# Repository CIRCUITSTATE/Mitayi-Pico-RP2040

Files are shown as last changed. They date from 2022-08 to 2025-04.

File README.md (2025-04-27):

# Mitayi-Pico-D1

[**Mitayi-Pico-D1**](https://github.com/CIRCUITSTATE/Mitayi-Pico-RP2040) is the first development board from **CIRCUITSTATE Electronics**. The board is based on the **RP2040** microcontroller from Raspberry Pi and is designed after the official [**Raspberry Pi Pico**](https://www.raspberrypi.com/products/raspberry-pi-pico/) board, but adds a few improvements over it. **D1** is the first design variant of Mitayi-Pico. Mitayi-Pico is not pin-compatible with the official Raspberry Pi Pico. The schematic and PCB are designed with **KiCad**, an open-source EDA tool. All the design files of Mitayi-Pico are completely open-source and released under the MIT license.

## Features & Differences

- **RP2040** dual-core, 133MHz ARM Cortex M0+ microcontroller.
- Up to 16 MB Flash memory in `SOIC-8` package.
- USB-C for power and communication.
- USB solder pads.
- **MIC5219** LDO with 3.3V, 500 mA output.
- Power indication LED.
- `RESET` button.
- `BOOTSEL` button reconfigurable as GPIO input button.
- Debug LED with GPIO solder jumper.
- Breaks out all MCU GPIO pins.
- **EXP8** expansion connector in 2x4 2.54mm pin header. Breaks out SPI, UART and I2C.
- 3-pin SWD connector.
- Uses 0402 or larger SMD packages.
- **Mitayi-Pico is not pin-compatible with the official Raspberry Pi Pico.**
- Same dimensions of 21 mm x 50 mm, with almost the same positions for mounting holes.
- Completely open-source design made with KiCad 9.

## Design

- **Parent Project:** Mitayi-Pico
- **Variant:** [Mitayi-Pico-D1](https://github.com/CIRCUITSTATE/Mitayi-Pico-RP2040)
- **Author:** Vishnu Mohanan (@vishnumaiea)
- **Latest Revision:** `R0.6`
- **Layer Count:** 2
- **Thickness:** 1 mm
- **Dimensions:** 51 x 21 mm
- **EDA Tool:** KiCad V9
- **License:** MIT

## Contributing

If you would like to contribute this project, you are welcome to post issues and feature requests on the **Issues** page. If you fork this project and created a new variant, you can let us know about it and get a unique identifier assigned for your project. The ID takes the following form.

```
Y<digit><letter><digit>
```

`Y` – Constant prefix.

`<digit>` – Digits from 0–9

`<letter>` – Characters from A–Z.

**Examples:**

```
Y1A1
Y1A2
```

## References

- [**Raspberry Pi Pico** - Product Page](https://www.raspberrypi.com/products/raspberry-pi-pico/)

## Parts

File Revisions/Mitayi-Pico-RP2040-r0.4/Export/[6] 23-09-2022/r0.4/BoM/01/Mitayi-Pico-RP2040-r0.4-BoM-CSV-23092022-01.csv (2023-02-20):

Id | Designator | Package | Quantity | Designation | Supplier and ref
1 | JP5 | Solder-Jumper_2P_Open_0402 | 1 | DEB_EN
2 | D2 | LED_0603_1608Metric | 1 | DBG_LED
3 | C17,C18 | C_0402_1005Metric_Pad0.74x0.62mm_HandSolder | 2 | 30pF
4 | C12,C6,C11,C10,C2,C1,C9,C8,C7 | C_0402_1005Metric_Pad0.74x0.62mm_HandSolder | 9 | 100n
5 | C13,C15 | C_0603_1608Metric | 2 | 10u
6 | C19,C5,C4 | C_0402_1005Metric_Pad0.74x0.62mm_HandSolder | 3 | 1u
7 | R2,R10 | R_0402_1005Metric_Pad0.72x0.64mm_HandSolder | 2 | 1k
8 | R7,R8 | R_0402_1005Metric_Pad0.72x0.64mm_HandSolder | 2 | 470R
9 | H3,H2,H4,H1 | MountingHole_2.2mm_M2 | 4 | MountingHole
10 | U3 | RP2040-QFN-56 | 1 | RP2040
11 | R5,R6 | R_0402_1005Metric_Pad0.72x0.64mm_HandSolder | 2 | 27R
12 | U1 | SOIC-8_5.23x5.23mm_P1.27mm | 1 | W25Q128JVS
13 | R1 | R_0402_1005Metric_Pad0.72x0.64mm_HandSolder | 1 | DNP
14 | J5 | PinHeader_1x03_P2.54mm_Vertical | 1 | SWD
15 | JP1 | Solder-Jumper_2P_Open_0402 | 1 | AREF_SEL
16 | R9 | R_0402_1005Metric_Pad0.72x0.64mm_HandSolder | 1 | 10K
17 | J2 | Korean-Hroparts-Elec_TYPE-C-31-M-12 | 1 | USB_C_Receptacle_USB2.0
18 | C16 | C_0402_1005Metric_Pad0.74x0.62mm_HandSolder | 1 | 470pF
19 | JP4 | Solder-Jumper_2P_Open_0402 | 1 | VR1_CE
20 | R4,R3,R11 | R_0402_1005Metric_Pad0.72x0.64mm_HandSolder | 3 | 5.1K
21 | Y1 | Crystal_SMD_3225-4Pin_3.2x2.5mm | 1 | YIC-12M20P2/XT324-10/10
22 | D1 | D_SOD-323_HandSoldering | 1 | PMEG4005EJ
23 | D3 | LED_0603_1608Metric | 1 | POW_LED
24 | J6 | USB_Micro-B_Molex-105017-0001 | 1 | USB_B_Micro
25 | SW1 | CK_SW_SPST_UK-B0273-SP25Y | 1 | Reset
26 | J3 | PinHeader_1x20_2H_P2.54mm_Vertical | 1 | Header_1
27 | C14 | CP_EIA-2012-12_Kemet-R | 1 | 2.2uF
28 | U2 | SOT-23-5 | 1 | MIC5219-3.3YM5
29 | SW2 | CK_SW_SPST_UK-B0273-SP25Y | 1 | UBUT
30 | J1 | PinHeader_2x04_P2.54mm_Vertical | 1 | EXP8
31 | JP6 | Solder-Jumper_3P_Open_0402 | 1 | UBUT_SEL
32 | J4 | PinHeader_1x20_2H_P2.54mm_Vertical | 1 | Header_2

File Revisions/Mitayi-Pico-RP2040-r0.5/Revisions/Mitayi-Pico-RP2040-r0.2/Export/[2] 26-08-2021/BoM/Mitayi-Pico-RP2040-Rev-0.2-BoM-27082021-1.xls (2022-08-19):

Id | Reference | Value | Package | Quantity | Notes | MPN | LCSC Part # | Unit Price (INR) | Order Price (INR) | Min\Mult Order Qty
1 | C11,C5,C10,C9,C2,C1,C17,C8,C7,C6 | 100n | C_0402_1005Metric_Pad0.74x0.62mm_HandSolder | 10 |  | CC0402KRX5R6BB104 (https://lcsc.com/product-detail/Multilayer-Ceramic-Capacitors-MLCC-SMD-SMT_YAGEO-CC0402KRX5R6BB104_C129131.html) | C129131 (https://lcsc.com/product-detail/Multilayer-Ceramic-Capacitors-MLCC-SMD-SMT_YAGEO-CC0402KRX5R6BB104_C129131.html) | 0.3765 | 3.77 | 50\50
2 | C12 | 2.2uF | CP_EIA-2012-12_Kemet-R | 1 |  | CA45-A-16V-2.2uF-M (https://lcsc.com/product-detail/Tantalum-Capacitors_CEC-Shenzhen-Zhenhua-XinYun-Elec-CA45-A-16V-2-2uF-M_C688947.html) | C688947 (https://lcsc.com/product-detail/Tantalum-Capacitors_CEC-Shenzhen-Zhenhua-XinYun-Elec-CA45-A-16V-2-2uF-M_C688947.html) | 6.9761 | 6.98 | 5\5
3 | C14,C13 | 10u | C_0603_1608Metric | 2 |  | LMK107BJ106MALTD (https://lcsc.com/product-detail/Multilayer-Ceramic-Capacitors-MLCC-SMD-SMT_Taiyo-Yuden-LMK107BJ106MALTD_C18800.html) | C18800 (https://lcsc.com/product-detail/Multilayer-Ceramic-Capacitors-MLCC-SMD-SMT_Taiyo-Yuden-LMK107BJ106MALTD_C18800.html) | 1.0926 | 2.19 | 50\50
4 | C15 | 470pF | C_0402_1005Metric_Pad0.74x0.62mm_HandSolder | 1 |  | 0402N471J500CT (https://lcsc.com/product-detail/Multilayer-Ceramic-Capacitors-MLCC-SMD-SMT_Walsin-Tech-Corp-0402N471J500CT_C295986.html) | C295986 (https://lcsc.com/product-detail/Multilayer-Ceramic-Capacitors-MLCC-SMD-SMT_Walsin-Tech-Corp-0402N471J500CT_C295986.html) | 0.192 | 0.19 | 100\100
5 | C16,C4,C3 | 1u | C_0402_1005Metric_Pad0.74x0.62mm_HandSolder | 3 |  | 0402F105M100NT (https://lcsc.com/product-detail/Multilayer-Ceramic-Capacitors-MLCC-SMD-SMT_FH-Guangdong-Fenghua-Advanced-Tech-0402F105M100NT_C157621.html) | C157621 (https://lcsc.com/product-detail/Multilayer-Ceramic-Capacitors-MLCC-SMD-SMT_FH-Guangdong-Fenghua-Advanced-Tech-0402F105M100NT_C157621.html) | 0.2289 | 0.69 | 100\100
6 | C18,C19 | 27p | C_0402_1005Metric_Pad0.74x0.62mm_HandSolder | 2 |  | 0402CG270J500NT (https://lcsc.com/product-detail/Multilayer-Ceramic-Capacitors-MLCC-SMD-SMT_FH-Guangdong-Fenghua-Advanced-Tech-0402CG270J500NT_C1557.html) | C1557 (https://lcsc.com/product-detail/Multilayer-Ceramic-Capacitors-MLCC-SMD-SMT_FH-Guangdong-Fenghua-Advanced-Tech-0402CG270J500NT_C1557.html) | 0.1108 | 0.22 | 100\100
7 | D1 | DEBUG_LED | C_0603_1608Metric_Pad1.08x0.95mm_HandSolder | 1 |  | LTST-C191KSKT (https://lcsc.com/product-detail/Light-Emitting-Diodes-LED_Lite-On-LTST-C191KSKT_C125100.html) | C125100 (https://lcsc.com/product-detail/Light-Emitting-Diodes-LED_Lite-On-LTST-C191KSKT_C125100.html) | 1.8234 | 1.82 | 20\20
8 | D2 | MBR1020VL | D_SOD-123F | 1 |  | 1N5819W (https://lcsc.com/product-detail/Schottky-Barrier-Diodes-SBD_Shandong-Jingdao-Microelectronics-1N5819W_C169540.html) | C169540 (https://lcsc.com/product-detail/Schottky-Barrier-Diodes-SBD_Shandong-Jingdao-Microelectronics-1N5819W_C169540.html) | 7.21 | 7.21 | 5\5
9 | J1 | USB_C_Receptacle_USB2.0 | Korean-Hroparts-Elec_TYPE-C-31-M-12 | 1 |  | TYPE-C-31-M-12 (https://lcsc.com/product-detail/USB-Connectors_Korean-Hroparts-Elec-TYPE-C-31-M-12_C165948.html) | C165948 (https://lcsc.com/product-detail/USB-Connectors_Korean-Hroparts-Elec-TYPE-C-31-M-12_C165948.html) | 23.298 | 23.3 | 1\1
10 | J2 | Header_1 | PinHeader_1x20_2H_P2.54mm_Vertical | 1 | DNP |  |  |  |  | 100\100
11 | J3 | Header_2 | PinHeader_1x20_2H_P2.54mm_Vertical | 1 | DNP |  |  |  |  | 100\100
12 | J4 | USB Boot | R_0603_1608Metric_Pad0.98x0.95mm_HandSolder | 1 | DNP |  |  |  |  | 100\100
13 | J5 | SWD | PinHeader_1x03_P2.54mm_Vertical | 1 | DNP |  |  |  |  | 100\100
14 | J6 | USB_B_Micro | USB_Micro-B_Molex-105017-0001 | 1 |  | MicroXNJ (https://lcsc.com/product-detail/USB-Connectors_SHOU-HAN-MicroXNJ_C404969.html) | C404969 (https://lcsc.com/product-detail/USB-Connectors_SHOU-HAN-MicroXNJ_C404969.html) |  |  | 100\100
15 | JP1 | VR1_IN | R_0402_1005Metric | 1 | DNP |  |  |  |  | 5\5
16 | JP2 | VR2_OUT | R_0402_1005Metric | 1 | DNP |  |  |  |  | 5\5
17 | JP3 | VR1_BP | R_0402_1005Metric | 1 | DNP |  |  |  |  | 5\5
18 | JP4 | VR1_CE | R_0402_1005Metric | 1 | DNP
19 | JP5 | AREF | R_0402_1005Metric | 1 | DNP
20 | JP6 | DEB_EN | R_0402_1005Metric | 1 | DNP
21 | R1 | DNP | R_0402_1005Metric_Pad0.72x0.64mm_HandSolder | 1 | DNP
22 | R2,R3 | 1k | R_0402_1005Metric_Pad0.72x0.64mm_HandSolder | 2 |  | RMC04021K1%N (https://lcsc.com/product-detail/Chip-Resistor-Surface-Mount_TyoHM-RMC04021K1-N_C269675.html) | C269675 (https://lcsc.com/product-detail/Chip-Resistor-Surface-Mount_TyoHM-RMC04021K1-N_C269675.html) | 0.1625 | 0.33
23 | R4 | 470R | R_0402_1005Metric_Pad0.72x0.64mm_HandSolder | 1 |  | RTT024700FTH (https://lcsc.com/product-detail/Chip-Resistor-Surface-Mount_RALEC-RTT024700FTH_C103054.html) | C103054 (https://lcsc.com/product-detail/Chip-Resistor-Surface-Mount_RALEC-RTT024700FTH_C103054.html) | 0.0591 | 0.06
24 | R5,R6 | 27R | R_0402_1005Metric_Pad0.72x0.64mm_HandSolder | 2 |  | 0402WGF270JTCE (https://lcsc.com/product-detail/Chip-Resistor-Surface-Mount_UNI-ROYAL-Uniroyal-Elec-0402WGF270JTCE_C25100.html) | C25100 (https://lcsc.com/product-detail/Chip-Resistor-Surface-Mount_UNI-ROYAL-Uniroyal-Elec-0402WGF270JTCE_C25100.html) | 0.0517 | 0.1
25 | R8,R7 | 5.1K | R_0402_1005Metric_Pad0.72x0.64mm_HandSolder | 2 |  | 0402WGF5101TCE (https://lcsc.com/product-detail/Chip-Resistor-Surface-Mount_UNI-ROYAL-Uniroyal-Elec-0402WGF5101TCE_C25905.html) | C25905 (https://lcsc.com/product-detail/Chip-Resistor-Surface-Mount_UNI-ROYAL-Uniroyal-Elec-0402WGF5101TCE_C25905.html) | 0.0517 | 0.1
26 | R9 | 10K | R_0402_1005Metric_Pad0.72x0.64mm_HandSolder | 1 |  | RC0402FR-0710KL (https://lcsc.com/product-detail/Chip-Resistor-Surface-Mount_YAGEO-RC0402FR-0710KL_C60490.html) | C60490 (https://lcsc.com/product-detail/Chip-Resistor-Surface-Mount_YAGEO-RC0402FR-0710KL_C60490.html) | 0.0591 | 0.06
27 | SW1 | Reset | CK_SW_SPST_UK-B0273-SP25Y | 1 |  | UK-B0273-SP25Y (https://lcsc.com/product-detail/Tactile-Switches_USAKRO-UK-B0273-SP25Y_C493285.html) | C493285 (https://lcsc.com/product-detail/Tactile-Switches_USAKRO-UK-B0273-SP25Y_C493285.html) | 9.1981 | 9.2
28 | U1 | NCP1117-3.3_SOT223 | SOT-223-3_TabPin2 | 1 |  | LD1117-3.3 (https://lcsc.com/product-detail/Linear-Voltage-Regulators-LDO_UMW-Youtai-Semiconductor-Co-Ltd-LD1117-3-3_C347229.html) | C347229 (https://lcsc.com/product-detail/Linear-Voltage-Regulators-LDO_UMW-Youtai-Semiconductor-Co-Ltd-LD1117-3-3_C347229.html)
29 | U2 | MIC5219-3.3YM5 | SOT-23-5 | 1 |  | ME6217C33M5G (https://lcsc.com/product-detail/Linear-Voltage-Regulators-LDO_MICRONE-Nanjing-Micro-One-Elec-ME6217C33M5G_C427602.html) | C427602 (https://lcsc.com/product-detail/Linear-Voltage-Regulators-LDO_MICRONE-Nanjing-Micro-One-Elec-ME6217C33M5G_C427602.html) | 7.7143 | 7.71
30 | U3 | W25Q128JVS | SOIC-8_5.23x5.23mm_P1.27mm | 1 |  | W25Q128JVSIQ (https://lcsc.com/product-detail/NOR-FLASH_Winbond-Elec-W25Q128JVSIQ_C113767.html) | C113767 (https://lcsc.com/product-detail/NOR-FLASH_Winbond-Elec-W25Q128JVSIQ_C113767.html) | 57 | 57
31 | U4 | RP2040 | RP2040-QFN-56 | 1 |  | RP2040-7-500 |  | 80 | 80
32 | Y1 | ABLS-12.000MHZ-B4-T | Crystal_SMD_3225-4Pin_3.2x2.5mm | 1 |  | S3212000181080 (https://lcsc.com/product-detail/Crystals_JGHC-S3212000181080_C390764.html) | C390764 (https://lcsc.com/product-detail/Crystals_JGHC-S3212000181080_C390764.html) | 8.5633 | 8.56
 |  |  |  |  |  |  | Total

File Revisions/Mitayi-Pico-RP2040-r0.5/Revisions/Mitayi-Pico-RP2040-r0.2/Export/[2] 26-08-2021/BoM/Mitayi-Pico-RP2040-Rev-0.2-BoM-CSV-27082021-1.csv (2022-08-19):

Id | Designator | Package | Quantity | Designation | Supplier and ref
1 | JP6 | R_0402_1005Metric | 1 | DEB_EN
2 | D1 | C_0603_1608Metric_Pad1.08x0.95mm_HandSolder | 1 | DEBUG_LED
3 | C18,C19 | C_0402_1005Metric_Pad0.74x0.62mm_HandSolder | 2 | 27p
4 | C11,C5,C10,C9,C2,C1,C17,C8,C7,C6 | C_0402_1005Metric_Pad0.74x0.62mm_HandSolder | 10 | 100n
5 | J4 | R_0603_1608Metric_Pad0.98x0.95mm_HandSolder | 1 | USB Boot
6 | JP3 | R_0402_1005Metric | 1 | VR1_BP
7 | C14,C13 | C_0603_1608Metric | 2 | 10u
8 | C16,C4,C3 | C_0402_1005Metric_Pad0.74x0.62mm_HandSolder | 3 | 1u
9 | R2,R3 | R_0402_1005Metric_Pad0.72x0.64mm_HandSolder | 2 | 1k
10 | R4 | R_0402_1005Metric_Pad0.72x0.64mm_HandSolder | 1 | 470R
11 | H3,H2,H4,H1 | MountingHole_2.2mm_M2 | 4 | MountingHole
12 | Y1 | Crystal_SMD_3225-4Pin_3.2x2.5mm | 1 | ABLS-12.000MHZ-B4-T
13 | U4 | RP2040-QFN-56 | 1 | RP2040
14 | R5,R6 | R_0402_1005Metric_Pad0.72x0.64mm_HandSolder | 2 | 27R
15 | U3 | SOIC-8_5.23x5.23mm_P1.27mm | 1 | W25Q128JVS
16 | R1 | R_0402_1005Metric_Pad0.72x0.64mm_HandSolder | 1 | DNF
17 | G*** | OSHW-Logo-4x3.6mm | 1 | LOGO
18 | JP1 | R_0402_1005Metric | 1 | VR1_IN
19 | J5 | PinHeader_1x03_P2.54mm_Vertical | 1 | SWD
20 | R9 | R_0402_1005Metric_Pad0.72x0.64mm_HandSolder | 1 | 10K
21 | J1 | Korean-Hroparts-Elec_TYPE-C-31-M-12 | 1 | USB_C_Receptacle_USB2.0
22 | C15 | C_0402_1005Metric_Pad0.74x0.62mm_HandSolder | 1 | 470pF
23 | JP4 | R_0402_1005Metric | 1 | VR1_CE
24 | R8,R7 | R_0402_1005Metric_Pad0.72x0.64mm_HandSolder | 2 | 5.1K
25 | D2 | D_SOD-123F | 1 | MBR1020VL
26 | J6 | USB_Micro-B_Molex-105017-0001 | 1 | USB_B_Micro
27 | SW1 | CK_SW_SPST_UK-B0273-SP25Y | 1 | Reset
28 | J2 | PinHeader_1x20_2H_P2.54mm_Vertical | 1 | Header_1
29 | C12 | CP_EIA-2012-12_Kemet-R | 1 | 2.2uF
30 | JP5 | R_0402_1005Metric | 1 | AREF
31 | U2 | SOT-23-5 | 1 | MIC5219-3.3YM5
32 | U1 | SOT-223-3_TabPin2 | 1 | NCP1117-3.3_SOT223
33 | G*** | Circuitstate-Logomark-27x3.8mm | 1 | LOGO
34 | JP2 | R_0402_1005Metric | 1 | VR2_OUT
35 | J3 | PinHeader_1x20_2H_P2.54mm_Vertical | 1 | Header_2

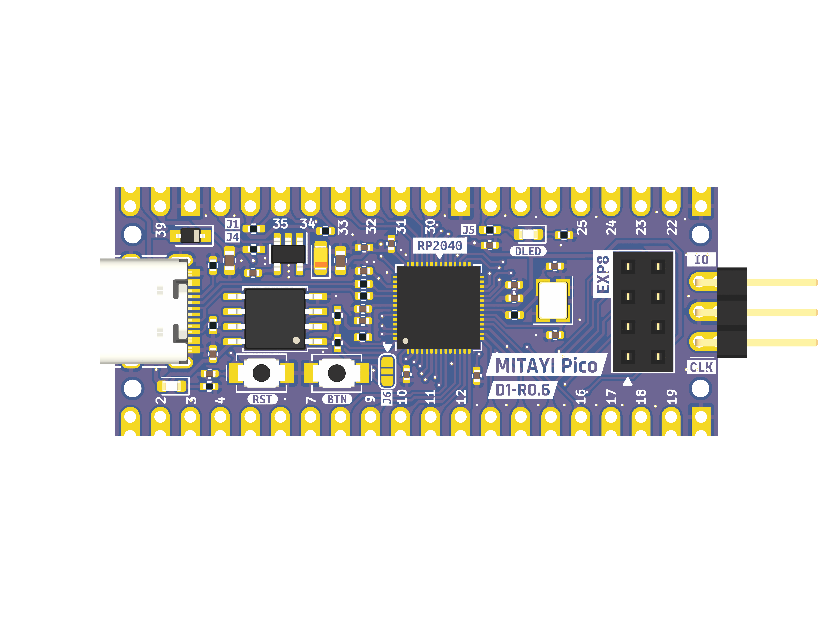
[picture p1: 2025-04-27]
Export/R0.6/2025-04-27/Renders/Mitayi-Pico-D1-R0.6-PCB-Parts-Front-27042025-1.png

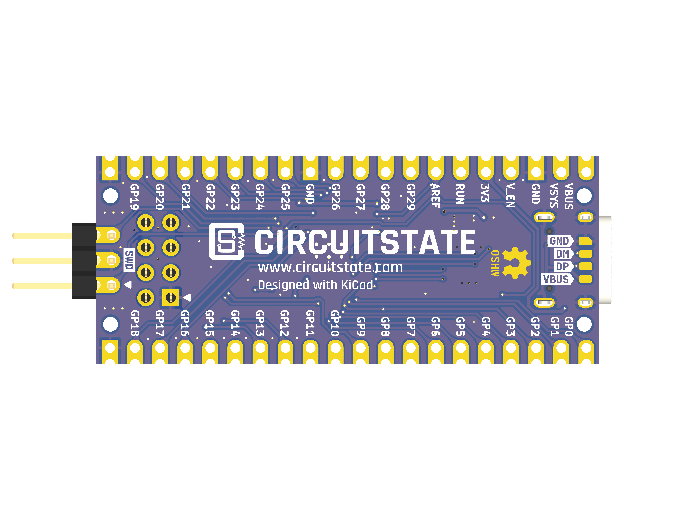
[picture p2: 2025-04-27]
Export/R0.6/2025-04-27/Renders/Mitayi-Pico-D1-R0.6-PCB-Parts-Back-27042025-1.png

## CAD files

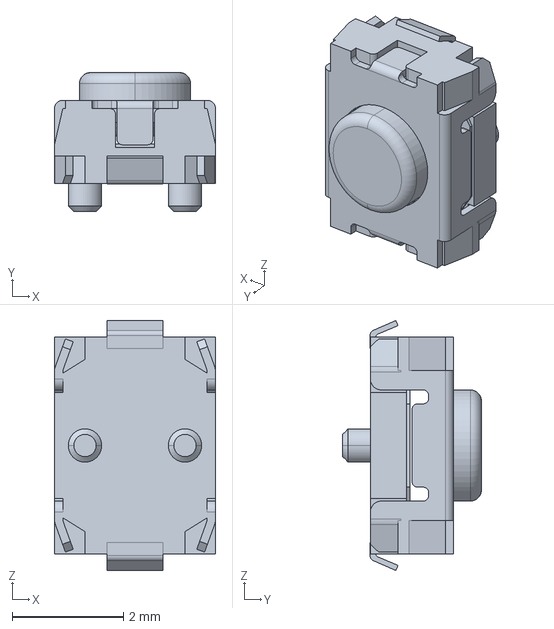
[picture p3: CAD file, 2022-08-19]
Revisions/Mitayi-Pico-RP2040-r0.5/Revisions/Mitayi-Pico-RP2040-r0.2/Parts/3D-Shapes/C&K-Tactile-Switch-PTS820J20KPSMTRLFS.stp
2.90 x 2.50 x 4.50 mm

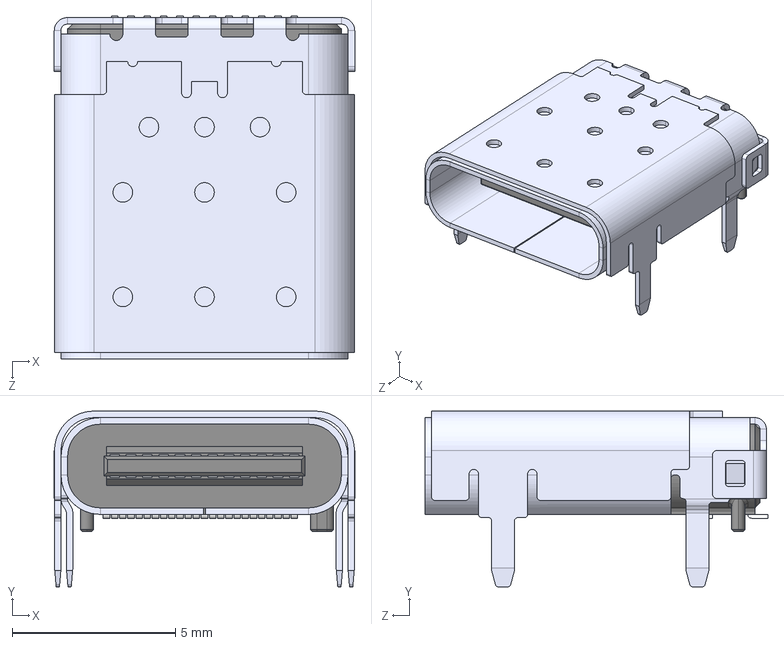
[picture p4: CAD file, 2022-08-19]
Revisions/Mitayi-Pico-RP2040-r0.5/Revisions/Mitayi-Pico-RP2040-r0.2/Parts/3D-Shapes/Amphenol-USB-Tyep-C-Receptacle-12401598E4#2A.STEP
9.20 x 5.38 x 10.5 mm

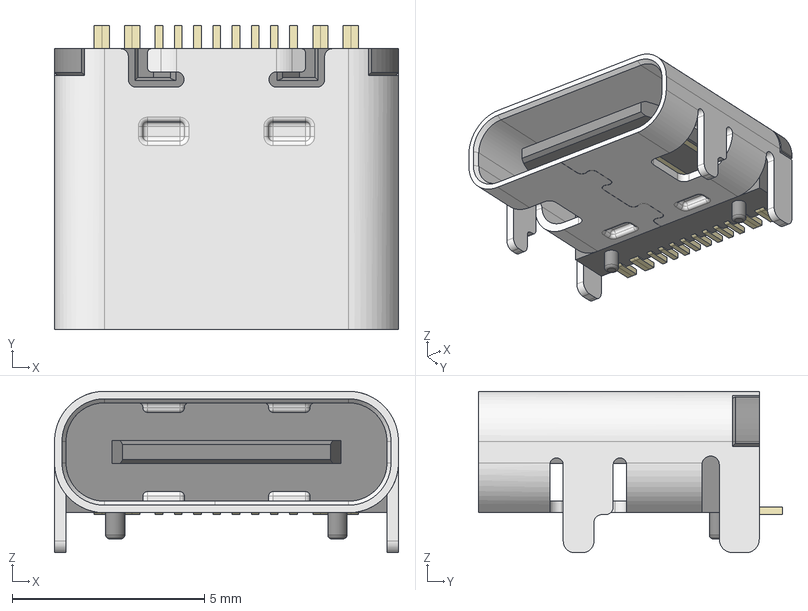
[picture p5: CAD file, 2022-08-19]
Revisions/Mitayi-Pico-RP2040-r0.5/Revisions/Mitayi-Pico-RP2040-r0.2/Parts/3D-Shapes/USB_Receptacle_HRO_TYPE-C-31-M-12.step
8.95 x 7.90 x 4.20 mm

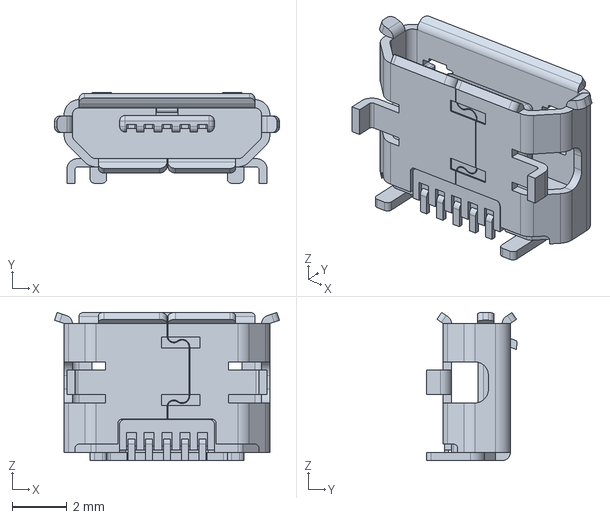
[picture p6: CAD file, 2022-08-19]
Revisions/Mitayi-Pico-RP2040-r0.5/Revisions/Mitayi-Pico-RP2040-r0.2/Parts/3D-Shapes/Molex-Micro-USB-Receptacle-1050170001.stp
8.20 x 3.30 x 5.40 mm

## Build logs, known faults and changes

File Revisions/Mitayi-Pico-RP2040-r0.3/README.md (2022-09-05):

View this project on [CADLAB.io](https://cadlab.io/project/25932). 





# Mitayi Pico r0.2

**Mitayi Pico** is the first development board from **CIRCUITSTATE Electronics**. It is a small development board based on the **RP2040** microcontroller from Raspberry Pi. The board is designed after the official Pico board from Raspberry Pi, but adds a few improvements over it.

The schematic and PCB are designed with **KiCad**, an open-source EDA tool. All the design files of Mitayi Pico are completely open-source and released under the MIT license.

## Features & Differences

* RP2040 dual-core, 133MHz ARM Cortex M0+ microcontroller.
* 16MB Flash memory in SOIC-8 package.
* Dual USB port options; Type-C and Micro-USB.
* Dual voltage regulators; AMS1117 and MIC5219.
* Reset button.
* Solder jumper on debug LED.
* Breaks out all GPIO pins.
* Uses 0402 or larger SMD packages.
* Component references on the silkscreen.
* **Mitayi-Pico is not pin-compatible with Raspberry Pico.**
* Same dimensions of 21 mm x 50 mm, with almost the same positions for mounting holes.
* Completely open-source design made with KiCad 6.

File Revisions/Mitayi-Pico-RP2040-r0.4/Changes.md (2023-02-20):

#
### **+05:30 09:54:46 AM 21-09-2022, Wednesday**

  * The r0.3 PCB looks so complicated with its routing. There are 180+ vias for a rather simple board. So I am going to remove all the tracks and start routing afresh. The r0.3 will be saved for reference anyway.

  * Starts 📢 **r0.4**.

#
### **+05:30 05:47:05 PM 05-09-2022, Monday**

  * Added new version info.
  * Added license info.
  * Connected with [CADLAB.io](https://cadlab.io/project/25932). 
  
#
### **+05:30 05:33:45 PM 27-08-2022, Saturday**

  * The crystal I selected was `YIC-12M20P2/XT324-10/10` from YIC. This is a **12MHz** crystal with 20pF required load capacitance. The four pin crystal has signals on the pins `1` and `3`. But unfortunately the r0.2 had the connections to pins `1` and `2`. Not only that, the `GND` pins of the crystals were never connected. I had to apply a jumper-fix on the r0.2 board as a temporary workaround to get the board working.

  * The capacitor value for the crystal has been changed to **20pF** from 25pF. This is because I thought the capacitors were the problem. RP2040 works fine with 20pF. The approximate capacitor value required is 30pF according to the calculations. 

  * Added a second push-button that can be selected between **Reset** (`RUN`) or **GPIO** (`GPIO2`) functions. The Reset function will only be needed rarely (for example, I used it to recover the RP2040 from a *soft-brick* after I changed the clock selection to 300MHz in the Arduino IDE). So in all other cases, the user can use the push-button as a user input button.

  * I also soldered the `R1` (10K) thinking that could have been the issue. Adding it did not change anything and the board works fine with that in place. R1 is only recommended for some versions of the Flash chip.

  * Removed the secondary voltage regulator.

  * Removed `AREF_VDD` jumper. It is now connected to 3.3V.

  * Starts 📢 **r0.3**.

#
### **+05:30 08:46:57 PM 19-08-2022, Friday**

  Added new `Revisions` folder. When a revision is completed, the projected can be saved to this folder using the **Save As** option in KiCad. This is in addition to generating a git revision. The project must be saved with the revision number at the end, for example ***"Mitayi-Pico-RP2040-r0.2"***. KiCad will complain about recursive folders but you can ignore them. Just delete the recursive `Revisions` folder from the the project that was just saved to the new `Revisions` folder.

  I just saved the version **🎯 r0.2**. Revisions, once saved, should not be modified. Make all the modifications on the root project.

#
### **+05:30 07:03:26 PM 26-08-2021, Thursday**

  I made a few mistakes in the v0.1 design. Some of the vias were placed on top of the pads. While this is not a big issue, PCBWay complained about this. They said the solder mask won't be applied on such vias, which is okay. Still, placing vias on pads is not a good idea. So I modified the design and moved all the vias from pads.

  Another issue is, whenever I am trying to run DRC check, KiCad would crash and leave some ghost processes that I can not terminate. I suspect the DRC crashes because the board has filleted tracks. Launching KiCad after crash is not a problem. It works fine after that. But I am not able to run DRC 😟

  Other than that, I added the Diode to VBUS and created the new VSYS signal. The pinouts has been changed. I removed BOOT_SEL from the header. Also, the supply pin side on the header is now compatible with RPi Pico. I am not going to add TVS diodes on the USB lines yet.

  Some of the via drill sizes were less than 0.3mm. I have now changed all of them to 0.5/0.3mm.

  I am going to keep the few filleted tracks and going to generate new Gerbers. Let's see what happens. This will be **🎯 r0.2**

#
### **+05:30 10:41:48 PM 25-08-2021, Wednesday**

  **Mitayi Pico** is an improved version of **Raspberry Pi Pico**. Mitayi Pico is based on the minimal design for **RP2040** published by RPi. Many cost cutting decisions were went into the design of RPi Pico. Lack of USB Type-C and Reset button are some of that. Mitayi Pico address that and many other limitations of RPi Pico. The differences are,

  1. The original Pico PCB design is created using Altium and files are available for download. But a similar design based on any affordable open source software such as KiCad was not available. Only the minimal board design was available.

  2. RPi Pico doesn't break out all the pins. Mitayi Pico does.

  3. RPi Pico uses buck-boost converter, which can be hard to find or costly. I wanted normal LDOs. Mitayi Pico has that + it has dual regulator option.

  4. RPi Pico's components are small (0201), making it harder to hand-solder. Mitayi uses 0402 and larger packages.

  5. RPi Pico only has Micro-USB. Mitayi Pico has both Type-C and Micro-USB options.

  6. Flash memory chip package is small and hard to hand-solder when we want to change the capacity. Mitayi uses SOIC-8 package which is easily solderable.

  7. RPi Pico doesn't have a RESET button. Mitayi does.

  8. RPi Pico and Mitayi Pico have different pinouts.

  9. Debug LED has solder jumper to disconnect it from the GPIO pin.

  10. RPi Pico and Mitayi Pico share the same dimensions of 21 mm x 50 mm, with almost the same positions for mounting holes.

  11. Component references are not present on the silkscreen of RPi Pico. Mitayi Pico has all the reference to help in manual assembly.

  The word "Mitayi" means Confectionary in Malayalam and Hindi. Mitayi will be a series of boards **CIRCUITSTATE Electronics** will develop. I am still not sure whether to name the new board "Pico" because that might create confusion with the original Pico. I have to find a unique name.

  I have finished the **🎯 v0.1** of the Pico. But it needs some changes. I will commit this version to be used as the base. The changes needed are,

  1. I need to add a reverse protection diode MBR120 to the VBUS line. This will create a new signal VSYS. It has to be broken out, replacing V_EN from the header.

  2. Have to add USB data line TVS diodes.

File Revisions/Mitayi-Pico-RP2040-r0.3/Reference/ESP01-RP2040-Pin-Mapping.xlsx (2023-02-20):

ESP01 | RP2040 | Functions | Arduino
VCC (8) | 3.3V (8)
GND (1) | GND (1)
TXD (5) | GP9 (2) | SCL0, RX1, SPI1-CS | RX2
RXD (4) | GP8 (7) | SDA0, TX1, SPI1-RX | TX2
RST (7) | GP14 (6) | SDA1, CTS0, SPI1-SCK | SPI1-SCK
CE (6) | GP13 (4) | SCL0, RX0, SPI1-CS | SPI1-CS
GPIO2 (2) | GP12 (3) | SDA0, TX0, SPI1-RX | SPI1-CIPO
GPIO0 (3) | GP15 (5) | SCL1, RTS1, SPI1-TX | SPI1-COPI

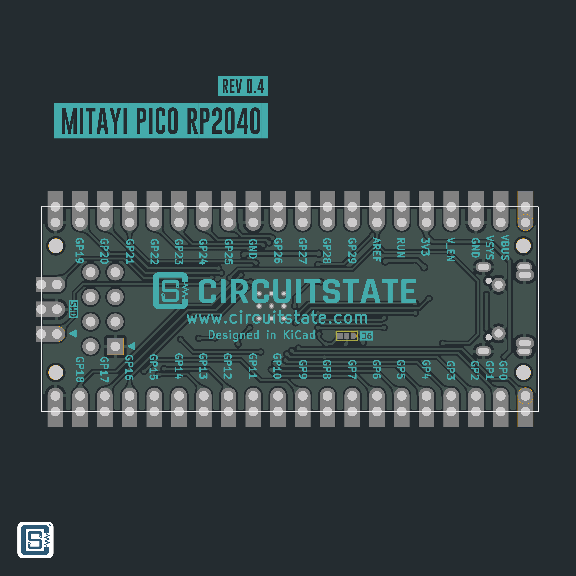
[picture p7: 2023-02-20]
Revisions/Mitayi-Pico-RP2040-r0.4/Export/[6] 23-09-2022/r0.4/Images/Mitayi-Pico-RP2040-r0.4-PCB-01-Back-2.png

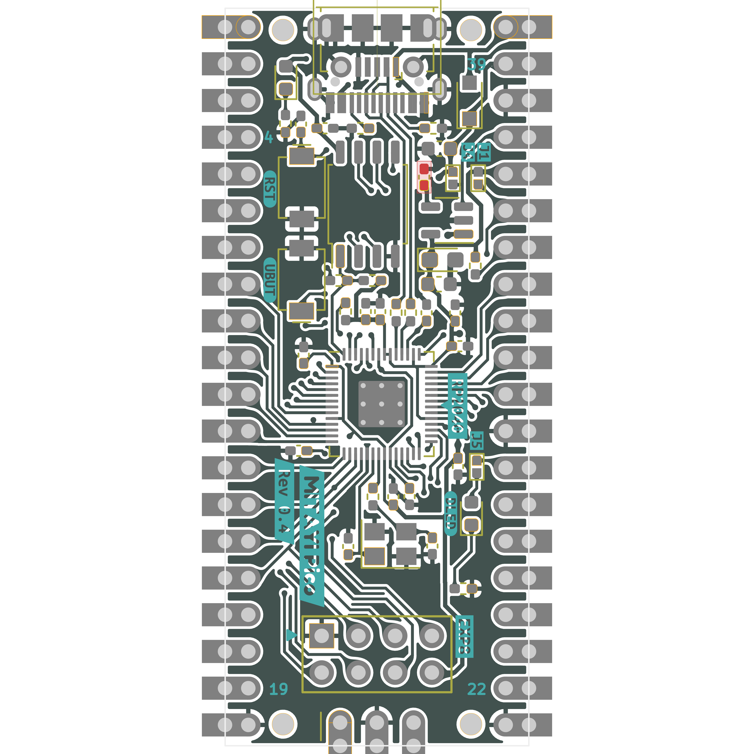
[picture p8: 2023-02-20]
Revisions/Mitayi-Pico-RP2040-r0.5/Revisions/Mitayi-Pico-RP2040-r0.4/Export/[6] 23-09-2022/r0.4/Images/Mitayi Pico - PCB.0.4.F (1).png

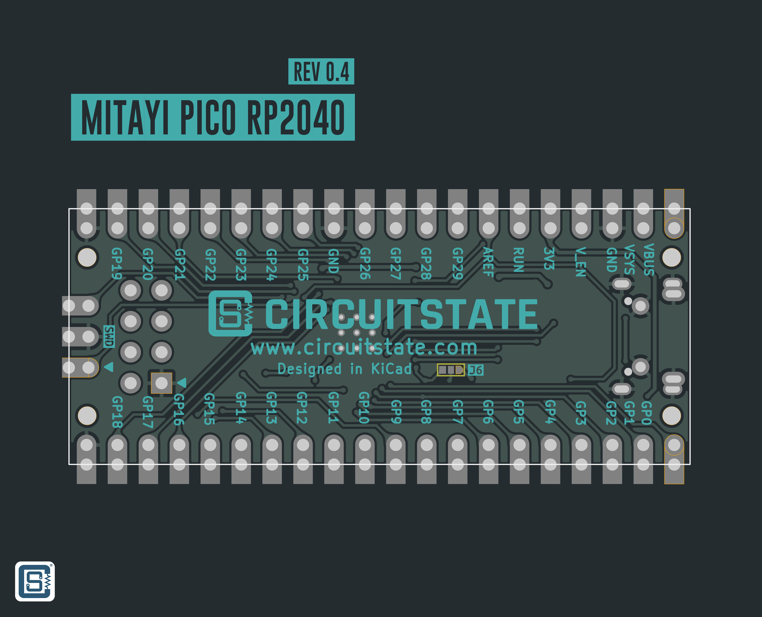
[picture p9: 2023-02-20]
Revisions/Mitayi-Pico-RP2040-r0.4/Export/[6] 23-09-2022/r0.4/Images/Mitayi-Pico-RP2040-r0.4-PCB-01-Back-1.png

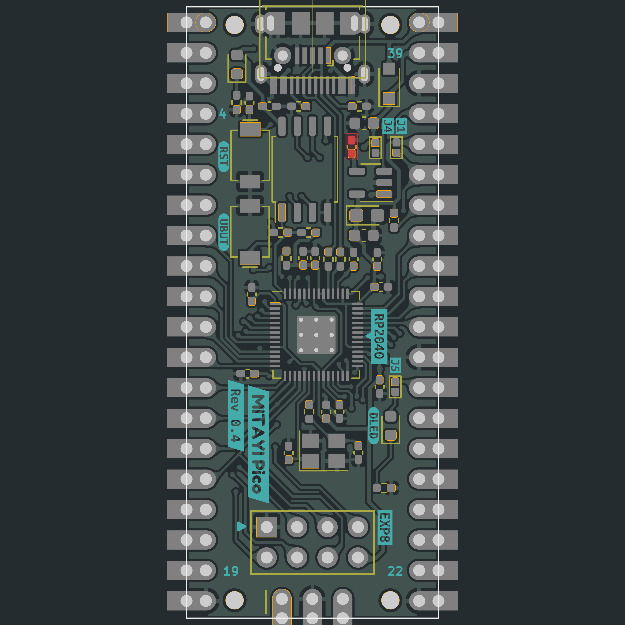
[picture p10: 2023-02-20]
Revisions/Mitayi-Pico-RP2040-r0.5/Revisions/Mitayi-Pico-RP2040-r0.4/Export/[6] 23-09-2022/r0.4/Images/Mitayi Pico - PCB.0.4.F.png

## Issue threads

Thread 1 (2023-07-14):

Missing Symbol / Footprint

hmaerki, 2023-07-14:
Hi Vishnu

I had a look at ths PCB and I like it a lot!

There is a symbol of U3 missing `CIRCUITSTATE-Microcontrollers:RP2040`
These footprints are missing:
CIRCUITSTATE-QFN:RP2040-QFN-56
JP5 (CIRCUITSTATE_Jumper_SMD:Solder-Jumper_2P_Open_0402
SW2 (CIRCUITSTATE_Switch_SMD:CK_SW_SPST_UK-B0273-SP25YG
CIRCUITSTATE-Graphics:Circuitstate-Logomark-27x3.8mm

Could you add this symbol/footprint please.

Thank you
    Hans

Keep going with you excellent work!

vishnumaiea, 2023-07-14:
Hi Hans. Glad you like it. The footprints you have mentioned are custom footprints I designed for the board. They were saved to local libraries in my system, not to the project folder. So you won't find them in the project folder. But, all footprints must be cached on the design files, even if they are not in your system. You can open a footprint in the footprint editor and "Save As" it somewhere else if you plan to reuse them on a different project.

Does KiCad throw any errors while trying to load the files on your side? If yes, could you please share a screenshot? I hope you are using the latest KiCad release.

Please let me know if this helps.

hmaerki, 2023-07-14:
Hi Vishnu

Thanks for your quick response!

I use

> Application: KiCad Schematic Editor x86_64 on x86_64
> Version: 7.0.6-7.0.6~ubuntu23.04.1, release build

You proposed
>  You can open a footprint in the footprint editor and "Save As"

I did:
Schema Editor -> U3 -> Properties ->
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

So I guess that footprint is not cached.

These are all the missinig footprints/symbols:

```
Error: Update symbol U3 from 'CIRCUITSTATE-Microcontrollers:RP2040' to 'CIRCUITSTATE-Microcontrollers:RP2040': *** symbol not found ***

Error: Updated footprint J4 (CIRCUITSTATE-Connector-Pin-Headers:PinHeader_1x20_2H_P2.54mm_Vertical): *** library footprint not found ***
Error: Updated footprint G*** (CIRCUITSTATE-Graphics:Circuitstate-Logomark-27x3.8mm): *** library footprint not found ***
Error: Updated footprint JP6 (CIRCUITSTATE_Jumper_SMD:Solder-Jumper_3P_Open_0402): *** library footprint not found ***
Error: Updated footprint SW2 (CIRCUITSTATE_Switch_SMD:CK_SW_SPST_UK-B0273-SP25Y): *** library footprint not found ***
Error: Updated footprint J3 (CIRCUITSTATE-Connector-Pin-Headers:PinHeader_1x20_2H_P2.54mm_Vertical): *** library footprint not found ***
Error: Updated footprint SW1 (CIRCUITSTATE_Switch_SMD:CK_SW_SPST_UK-B0273-SP25Y): *** library footprint not found ***
Error: Updated footprint JP4 (CIRCUITSTATE_Jumper_SMD:Solder-Jumper_2P_Open_0402): *** library footprint not found ***
Error: Updated footprint J2 (CIRCUITSTATE_Connector_USB:Korean-Hroparts-Elec_TYPE-C-31-M-12): *** library footprint not found ***
Error: Updated footprint JP1 (CIRCUITSTATE_Jumper_SMD:Solder-Jumper_2P_Open_0402): *** library footprint not found ***
Error: Updated footprint U3 (CIRCUITSTATE-QFN:RP2040-QFN-56): *** library footprint not found ***
Error: Updated footprint JP5 (CIRCUITSTATE_Jumper_SMD:Solder-Jumper_2P_Open_0402): *** library footprint not found ***
```

vishnumaiea, 2023-07-14:
Footprints are cached on the PCB files only. The schematic files will just have the library path as a string in the schematic field, which if you tried to locate will end in a "not found" error. But KiCad is smart enough to understand that, despite the footprint path provided in the schematic files missing on your system, you have valid footprints assigned in the PCB design file.

If you want to assign the footprints in the schematic file without errors, you must save the footprints from the PCB file to a custom library of yours.

Even better, the PCB editor has an export option called "Footprints to New Library" which will save all the footprints in the PCB file to a custom new library. Simply save it to your system and reassign the missing ones. It is better to save the new library inside your project folder so that KiCad will replace the absolute path name with a relative one.

hmaerki, 2023-07-14:
Thanks a lot - you are a hero!

I exported "Footprints to New Library". This worked great.

The issue is resolved.

Closed 2023-07-14.

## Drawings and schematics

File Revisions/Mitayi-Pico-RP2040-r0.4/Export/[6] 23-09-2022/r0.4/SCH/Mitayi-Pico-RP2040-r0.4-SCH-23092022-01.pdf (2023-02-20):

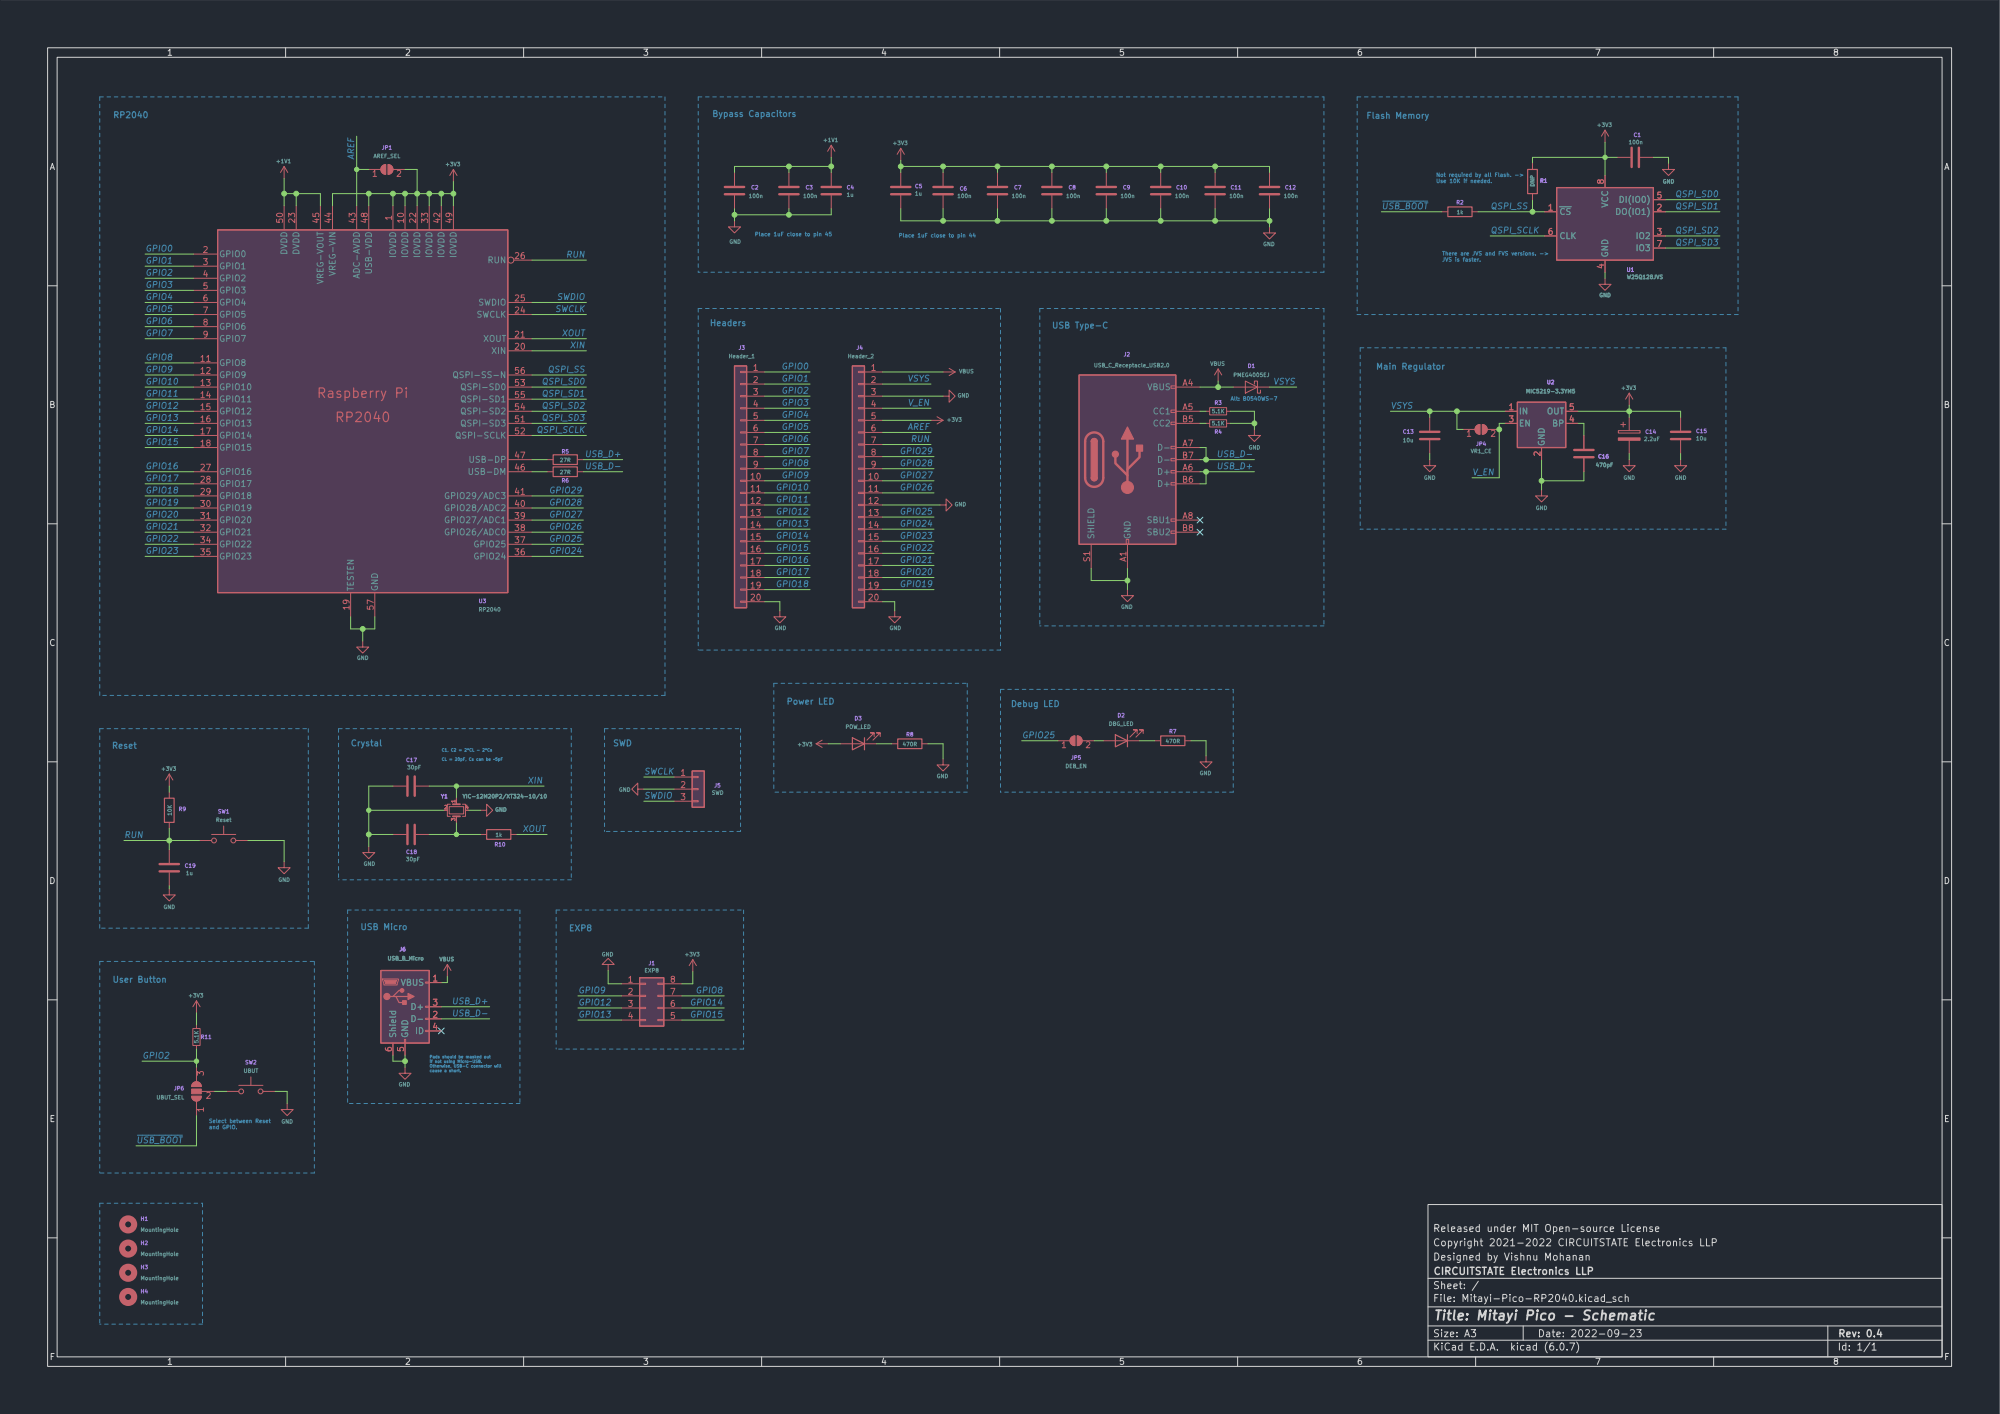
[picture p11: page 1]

1 IOVDD 10 GPIO8 11 GPIO9 12 GPIO10 13 GPIO11 14 GPIO12 15 GPIO13 16 GPIO14 17 GPIO15 18 TESTEN 19 GPIO0 2 XIN 20 XOUT 21 IOVDD 22 DVDD 23 SWCLK 24 SWDIO 25 RUN 26 GPIO16 27 GPIO17 28 GPIO18 29 GPIO1 3 GPIO19 30 GPIO20 31 GPIO21 32 IOVDD 33 GPIO22 34 GPIO23 35 GPIO24 36 GPIO25 37 GPIO26/ADC0 38 GPIO27/ADC1 39 GPIO2 4 GPIO28/ADC2 40 GPIO29/ADC3 41 IOVDD 42 ADC-AVDD 43 VREG-VIN 44 VREG-VOUT 45 USB-DM 46 USB-DP 47 USB-VDD 48 IOVDD 49 GPIO3 5 DVDD 50 QSPI-SD3 51 QSPI-SCLK 52 QSPI-SD0 53 QSPI-SD2 54 QSPI-SD1 55 QSPI-SS-N 56 GND 57 GPIO4 6 GPIO5 7 GPIO6 8 GPIO7 9

There are JVS and FVS versions. ->

Pads should be masked out

Select between Reset and GPIO.

Released under MIT Open-source License
Copyright 2021-2022 CIRCUITSTATE Electronics LLP
File: Mitayi-Pico-RP2040.kicad_sch Sheet: / CIRCUITSTATE Electronics LLP Designed by Vishnu Mohanan

Id: 1/1 Title: Mitayi Pico - Schematic

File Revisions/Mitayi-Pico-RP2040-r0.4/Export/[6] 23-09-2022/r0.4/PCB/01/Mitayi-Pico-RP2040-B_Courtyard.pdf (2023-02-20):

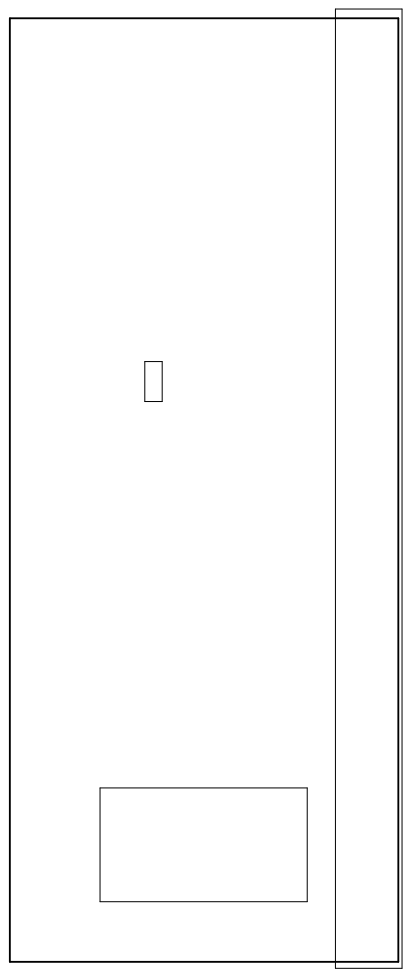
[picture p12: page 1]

Released under MIT Open-source License
Copyright 2021-2022 CIRCUITSTATE Electronics LLP
File: Mitayi-Pico-RP2040.kicad_pcb Sheet: CIRCUITSTATE Electronics LLP Designed by Vishnu Mohanan

Id: 1/1 Title: Mitayi Pico - PCB

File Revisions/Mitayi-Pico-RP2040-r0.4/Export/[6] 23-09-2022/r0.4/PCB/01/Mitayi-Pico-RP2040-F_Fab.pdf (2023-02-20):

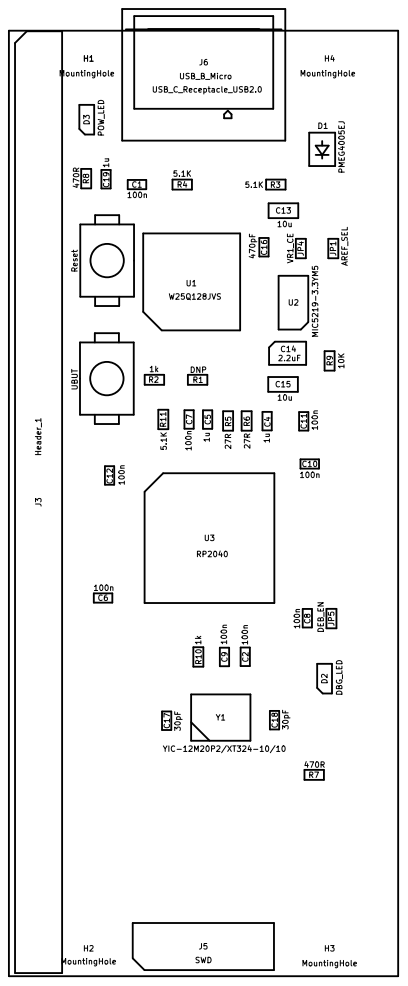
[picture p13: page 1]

10u C15 MountingHole H2
Released under MIT Open-source License DEB_EN JP5 DBG_LED D2 C17 30pF C12 100n
R7 MountingHole H3 1k R10

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

Id: 1/1 Title: Mitayi Pico - PCB

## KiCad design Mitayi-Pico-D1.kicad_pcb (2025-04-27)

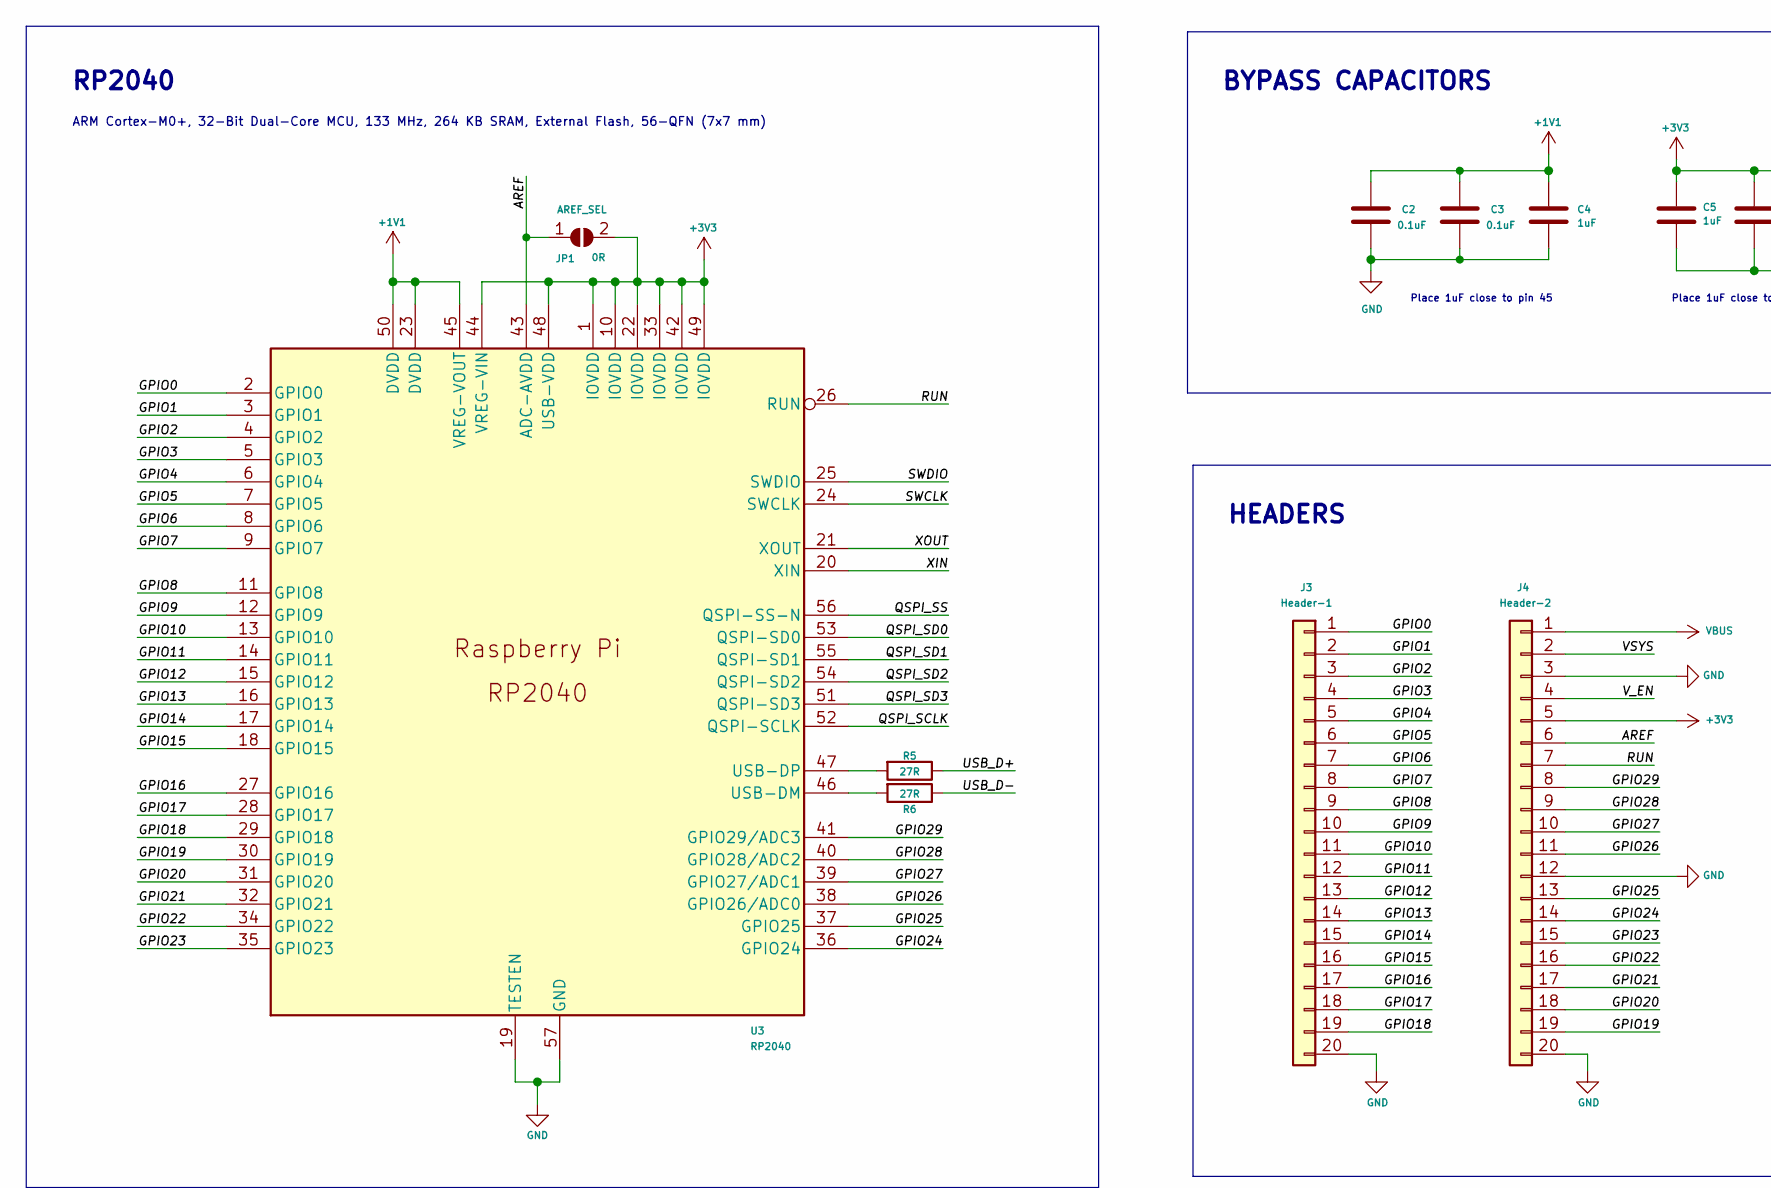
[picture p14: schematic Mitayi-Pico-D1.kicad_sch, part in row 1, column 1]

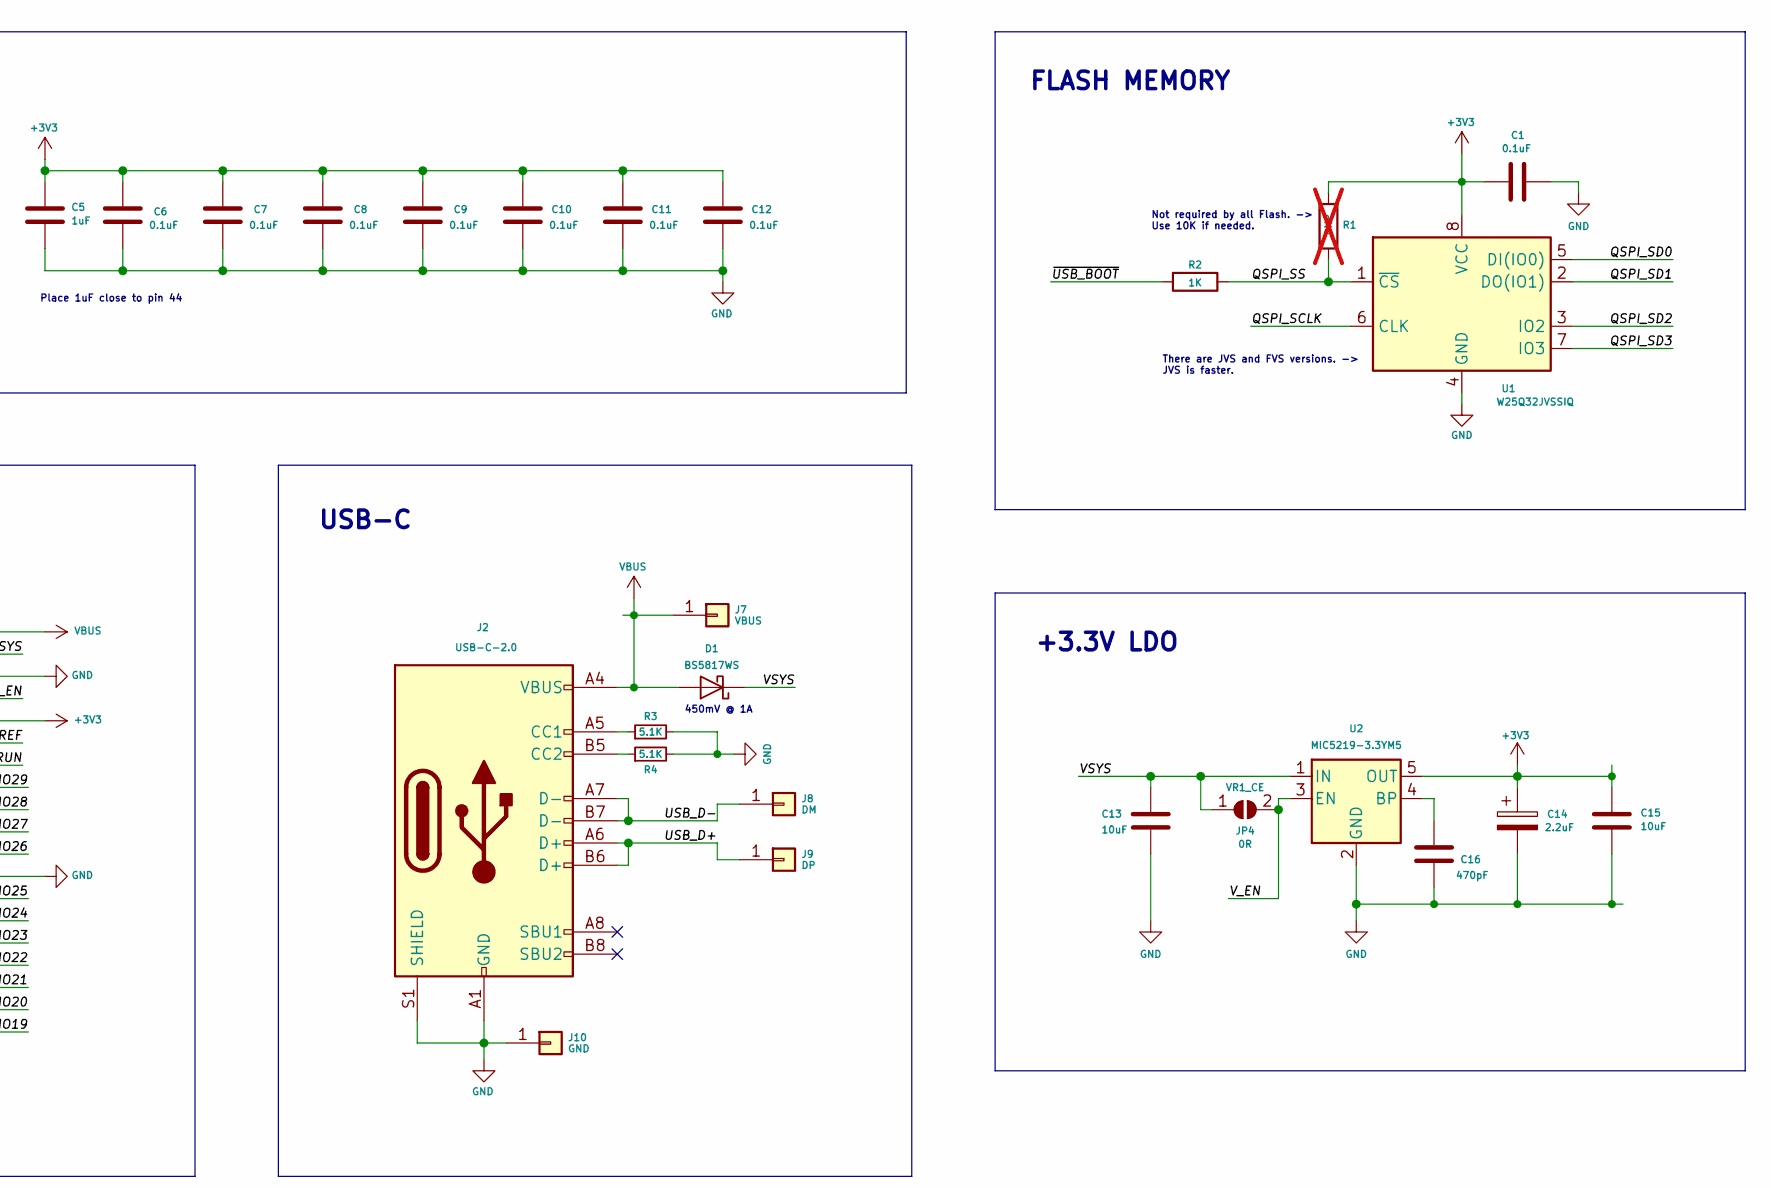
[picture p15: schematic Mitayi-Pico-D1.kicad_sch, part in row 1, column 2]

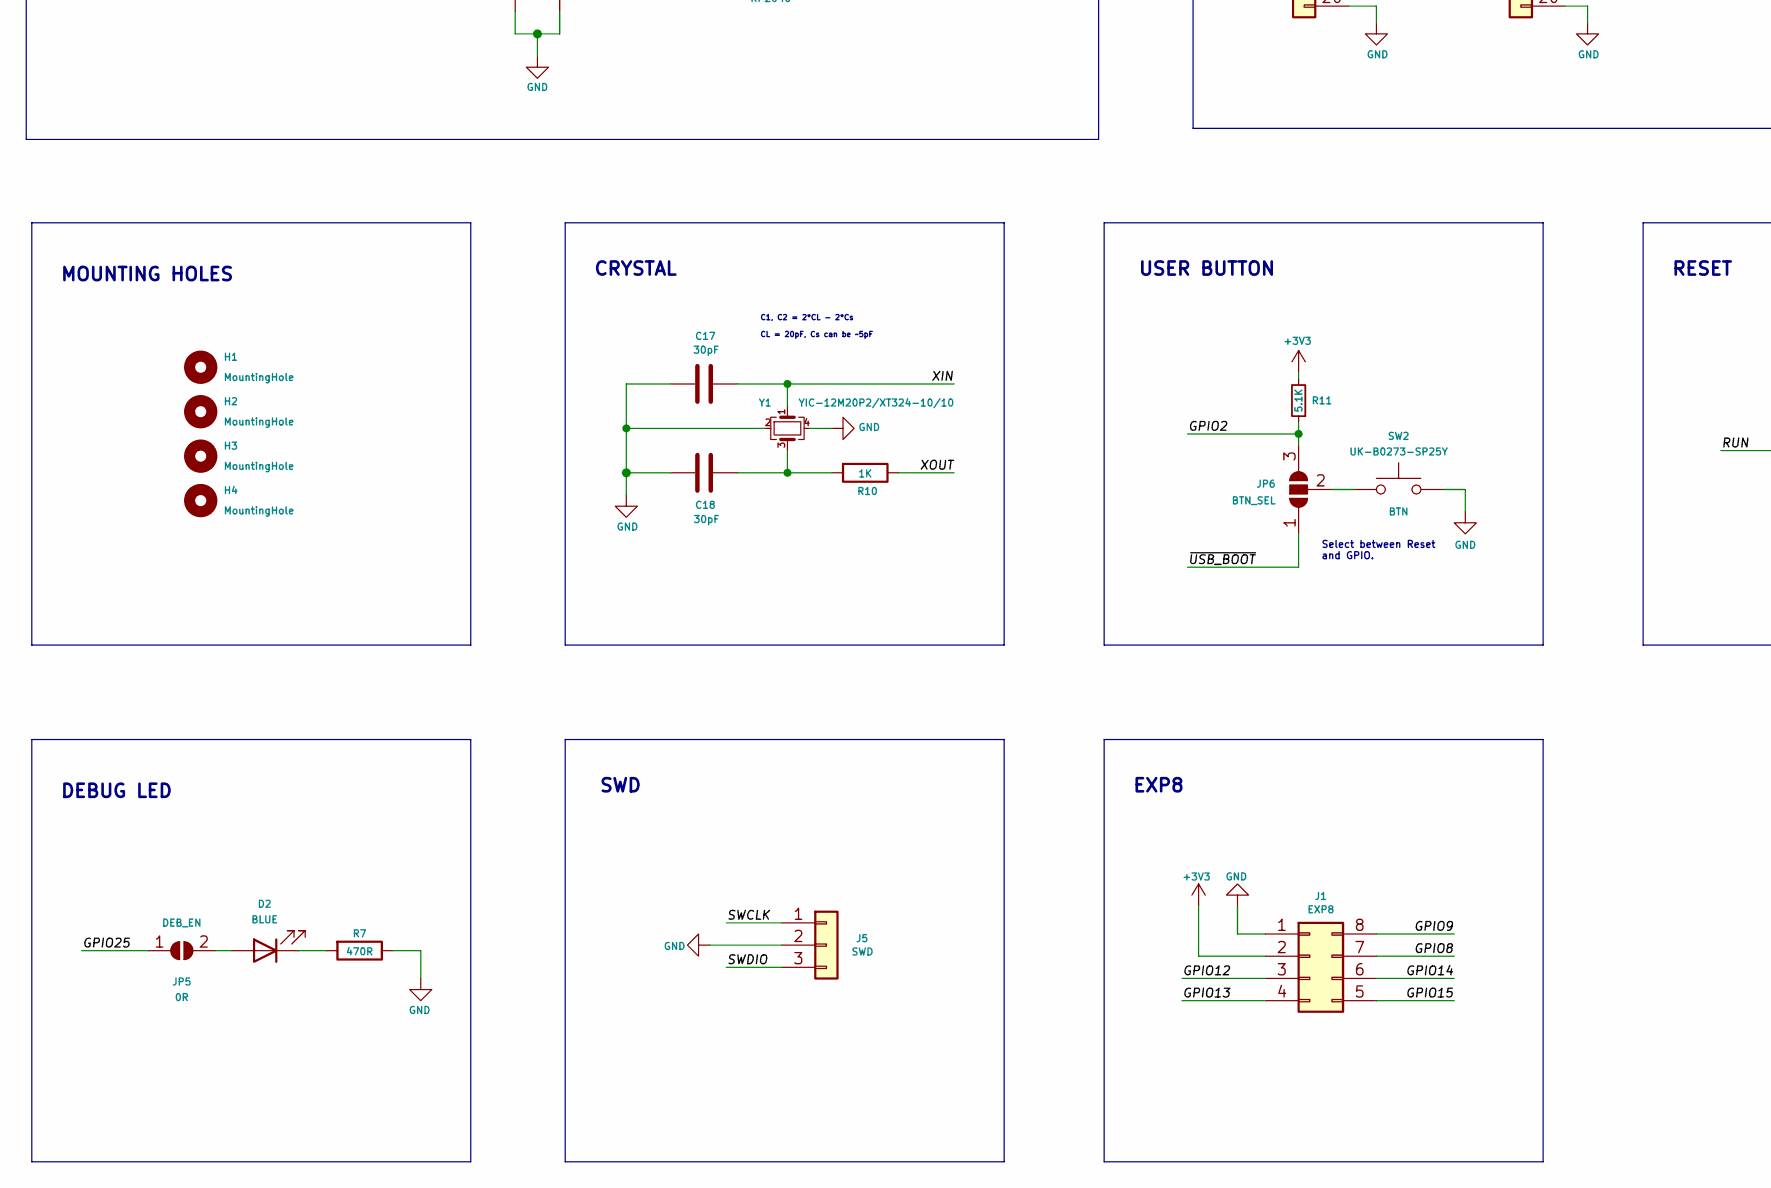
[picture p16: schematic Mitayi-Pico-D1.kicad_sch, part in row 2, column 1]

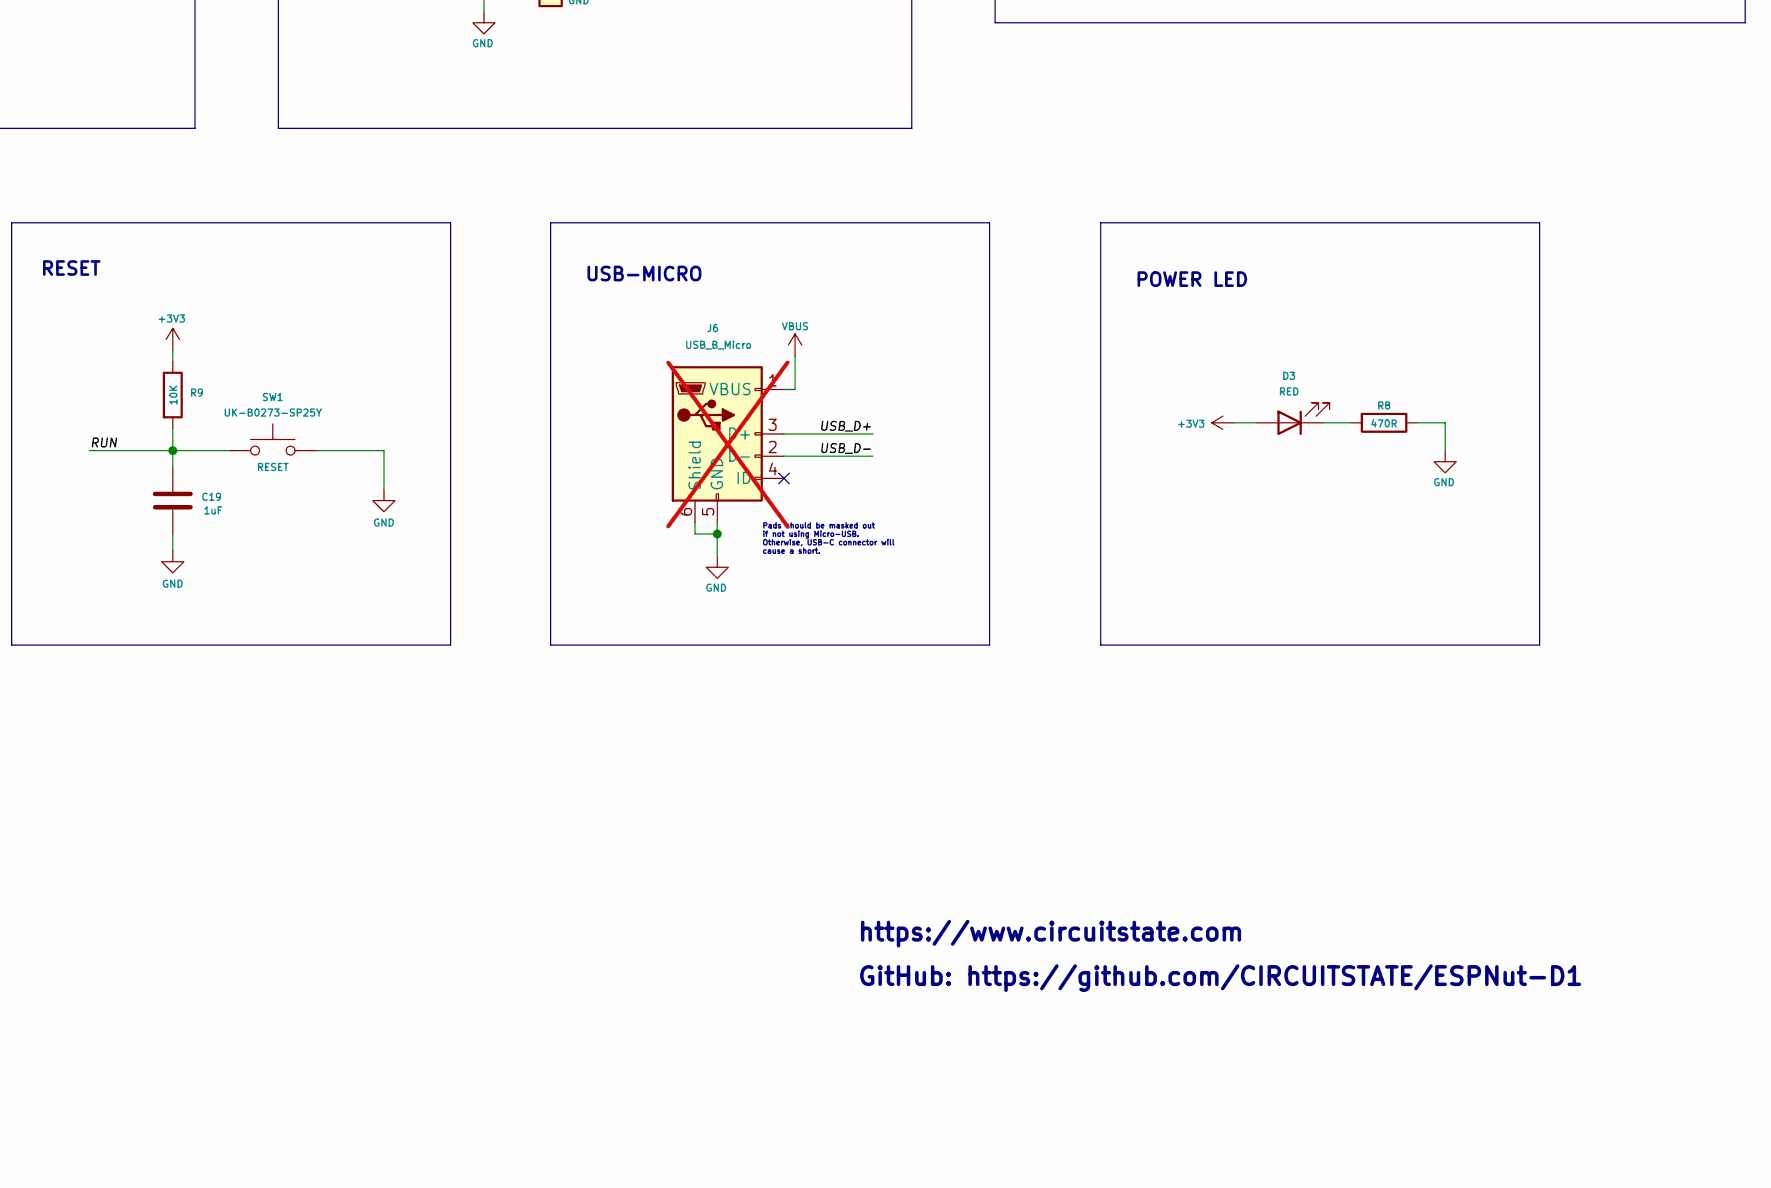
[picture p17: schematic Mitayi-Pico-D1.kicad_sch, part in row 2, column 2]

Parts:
C1, C2, C3, C6, C7, C8, C9, C10, C11, C12: 0.1uF; C_0402_1005Metric; MPN 0402B104K160CT
C4, C5, C19: 1uF; C_0402_1005Metric; MPN 0402X105K160CT
C13, C15: 10uF; C_0603_1608Metric; MPN 0603X106M6R3CT
C14: 2.2uF; CP_EIA-2012-12_Kemet-R; MPN TAJR225M016RNJ
C16: 470pF; C_0402_1005Metric; MPN 0402N471J500LT
C17, C18: 30pF; C_0402_1005Metric; MPN 0402N270J500LT
D1: BS5817WS; D_SOD-323_HandSoldering; MPN B5817WS
D2: BLUE; LED_0603_1608Metric; MPN 19-213/BHC-ZL1M2RY/3T
D3: RED; LED_0603_1608Metric; MPN 19-21SURC/S530-A2/TR8
H1, H2, H3, H4: MountingHole; MountingHole_2.2mm_M2; MPN DNP
J1: EXP8; PinHeader_2x04_P2.54mm_Vertical; MPN DNP
J2: USB-C-2.0; USB_C_Receptacle_HRO_TYPE-C-31-M-12; MPN HC-TYPE-C-16P-01A
J3: Header-1; PinHeader_1x20_2H_P2.54mm_Vertical; MPN DNP
J4: Header-2; PinHeader_1x20_2H_P2.54mm_Vertical; MPN DNP
J5: SWD; PinHeader_1x03_P2.54mm_Vertical; MPN DNP
J6: USB_B_Micro; USB_Micro-B_Molex-105017-0001; MPN DNP; not fitted
J7: VBUS; Solderpad_Rounded_Rectangle_0.8x1.3mm; MPN DNP
J8: DM; Solderpad_Rounded_Rectangle_0.8x1.3mm; MPN DNP
J9: DP; Solderpad_Rounded_Rectangle_0.8x1.3mm; MPN DNP
J10: GND; Solderpad_Rectangle_0.8x1.3mm_Chamfered; MPN DNP
JP1, JP4, JP5: 0R; R_0402_1005Metric_Pad0.72x0.64mm_HandSolder; MPN WR04X000PTL
JP6: BTN_SEL; SolderJumper-3_P0.83mm_Open_Rounded-Pad_0.85x1mm; MPN DNP
R1: DNP; R_0402_1005Metric; MPN DNP; not fitted
R2, R10: 1K; R_0402_1005Metric; MPN WR04X1001FTL
R3, R4, R11: 5.1K; R_0402_1005Metric; MPN WR04X5101FTL
R5, R6: 27R; R_0402_1005Metric; MPN WR04X27R0FTL
R7, R8: 470R; R_0402_1005Metric; MPN WR04X4700FTL
R9: 10K; R_0402_1005Metric; MPN WR04X1002FTL
SW1, SW2: UK-B0273-SP25Y; CK_SW_SPST_UK-B0273-SP25Y; MPN UK-B0273-SP25Y
U1: W25Q32JVSSIQ; SOIC-8_5.23x5.23mm_P1.27mm; MPN W25Q32JVSSIQ
U2: MIC5219-3.3YM5; SOT-23-5; MPN MIC5219-3.3YM5-TR
U3: RP2040; RP2040-QFN-56; MPN RP2040-B2
Y1: YIC-12M20P2/XT324-10/10; Crystal_SMD_3225-4Pin_3.2x2.5mm; MPN YIC-12M20P2/XT324-10/10

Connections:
+1V1: C2.1, C3.1, C4.1, U3.23 (DVDD), U3.45 (VREG-VOUT), U3.50 (DVDD)
+3V3: C1.1, C5.1, C6.1, C7.1, C8.1, C9.1, C10.1, C11.1, C12.1, C14.1, C15.1, D3.2 (A), J1.2, J4.5, JP1.2 (B), R1.1, R9.1, R11.2, U1.8 (VCC), U2.5 (OUT), U3.1 (IOVDD), U3.10 (IOVDD), U3.22 (IOVDD), U3.33 (IOVDD), U3.42 (IOVDD), U3.44 (VREG-VIN), U3.48 (USB-VDD), U3.49 (IOVDD)
/AREF: J4.6, JP1.1 (A), U3.43 (ADC-AVDD)
/GPIO0: J3.1, U3.2 (GPIO0)
/GPIO1: J3.2, U3.3 (GPIO1)
/GPIO2: J3.3, JP6.3 (B), R11.1, U3.4 (GPIO2)
/GPIO3: J3.4, U3.5 (GPIO3)
/GPIO4: J3.5, U3.6 (GPIO4)
/GPIO5: J3.6, U3.7 (GPIO5)
/GPIO6: J3.7, U3.8 (GPIO6)
/GPIO7: J3.8, U3.9 (GPIO7)
/GPIO8: J1.7, J3.9, U3.11 (GPIO8)
/GPIO9: J1.8, J3.10, U3.12 (GPIO9)
/GPIO10: J3.11, U3.13 (GPIO10)
/GPIO11: J3.12, U3.14 (GPIO11)
/GPIO12: J1.3, J3.13, U3.15 (GPIO12)
/GPIO13: J1.4, J3.14, U3.16 (GPIO13)
/GPIO14: J1.6, J3.15, U3.17 (GPIO14)
/GPIO15: J1.5, J3.16, U3.18 (GPIO15)
/GPIO16: J3.17, U3.27 (GPIO16)
/GPIO17: J3.18, U3.28 (GPIO17)
/GPIO18: J3.19, U3.29 (GPIO18)
/GPIO19: J4.19, U3.30 (GPIO19)
/GPIO20: J4.18, U3.31 (GPIO20)
/GPIO21: J4.17, U3.32 (GPIO21)
/GPIO22: J4.16, U3.34 (GPIO22)
/GPIO23: J4.15, U3.35 (GPIO23)
/GPIO24: J4.14, U3.36 (GPIO24)
/GPIO25: J4.13, JP5.1 (A), U3.37 (GPIO25)
/GPIO26: J4.11, U3.38 (GPIO26/ADC0)
/GPIO27: J4.10, U3.39 (GPIO27/ADC1)
/GPIO28: J4.9, U3.40 (GPIO28/ADC2)
/GPIO29: J4.8, U3.41 (GPIO29/ADC3)
/QSPI_SCLK: U1.6 (CLK), U3.52 (QSPI-SCLK)
/QSPI_SD0: U1.5 (DI(IO0)), U3.53 (QSPI-SD0)
/QSPI_SD1: U1.2 (DO(IO1)), U3.55 (QSPI-SD1)
/QSPI_SD2: U1.3 (IO2), U3.54 (QSPI-SD2)
/QSPI_SD3: U1.7 (IO3), U3.51 (QSPI-SD3)
/QSPI_SS: R1.2, R2.1, U1.1 (~CS), U3.56 (QSPI-SS-N)
/RUN: C19.1, J4.7, R9.2, SW1.1, U3.26 (RUN)
/SWCLK: J5.1, U3.24 (SWCLK)
/SWDIO: J5.3, U3.25 (SWDIO)
/USB_D+: J2.A6 (D+), J2.B6 (D+), J6.3 (D+), J9.1, R5.1
/USB_D-: J2.A7 (D-), J2.B7 (D-), J6.2 (D-), J8.1, R6.1
/VSYS: C13.1, D1.1 (K), J4.2, JP4.1 (A), U2.1 (IN)
/V_EN: J4.4, JP4.2 (B), U2.3 (EN)
/XIN: C17.1, U3.20 (XIN), Y1.1
/XOUT: R10.1, U3.21 (XOUT)
/~USB_BOOT: JP6.1 (A), R2.2
GND: C1.2, C2.2, C3.2, C4.2, C5.2, C6.2, C7.2, C8.2, C9.2, C10.2, C11.2, C12.2, C13.2, C14.2, C15.2, C16.2, C17.2, C18.2, C19.2, J1.1, J2.A1 (GND), J2.A12 (GND), J2.B1 (GND), J2.B12 (GND), J2.S1 (SHIELD), J3.20, J4.3, J4.12, J4.20, J5.2, J6.5 (GND), J6.6 (Shield), J10.1, R3.2, R4.2, R7.1, R8.1, SW1.2, SW2.2, U1.4 (GND), U2.2 (GND), U3.19 (TESTEN), U3.57 (GND), Y1.2, Y1.4
unnamed: C18.1, R10.2, Y1.3
unnamed: D2.2 (A), JP5.2 (B)
unnamed: D2.1 (K), R7.2
unnamed: D3.1 (K), R8.2
unnamed: J2.A5 (CC1), R3.1
unnamed: J2.B5 (CC2), R4.1
unnamed: JP6.2 (C), SW2.1
unnamed: C16.1, U2.4 (BP)
unnamed: R6.2, U3.46 (USB-DM)
unnamed: R5.2, U3.47 (USB-DP)
VBUS: D1.2 (A), J2.A4 (VBUS), J2.A9 (VBUS), J2.B4 (VBUS), J2.B9 (VBUS), J4.1, J6.1 (VBUS), J7.1

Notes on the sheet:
https://www.circuitstate.com
HEADERS
GitHub: https://github.com/CIRCUITSTATE/ESPNut-D1
+3.3V LDO
450mV @ 1A
POWER LED
Place 1uF close to pin 45
There are JVS and FVS versions. -> JVS is faster.
RP2040
EXP8
Pads should be masked out if not using Micro-USB. Otherwise, USB-C connector will cause a short.
FLASH MEMORY
Not required by all Flash. -> Use 10K if needed.
C1, C2 = 2*CL - 2*Cs CL = 20pF, Cs can be ~5pF
SWD
RESET
USB-MICRO
Place 1uF close to pin 44
CRYSTAL
Select between Reset and GPIO.
MOUNTING HOLES
BYPASS CAPACITORS
USB-C
DEBUG LED
USER BUTTON
ARM Cortex-M0+, 32-Bit Dual-Core MCU, 133 MHz, 264 KB SRAM, External Flash, 56-QFN (7x7 mm)

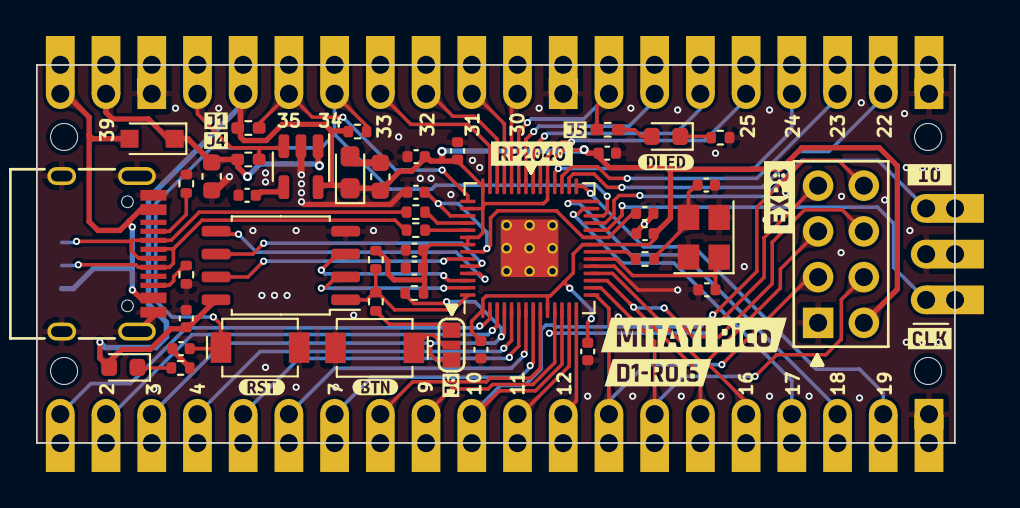
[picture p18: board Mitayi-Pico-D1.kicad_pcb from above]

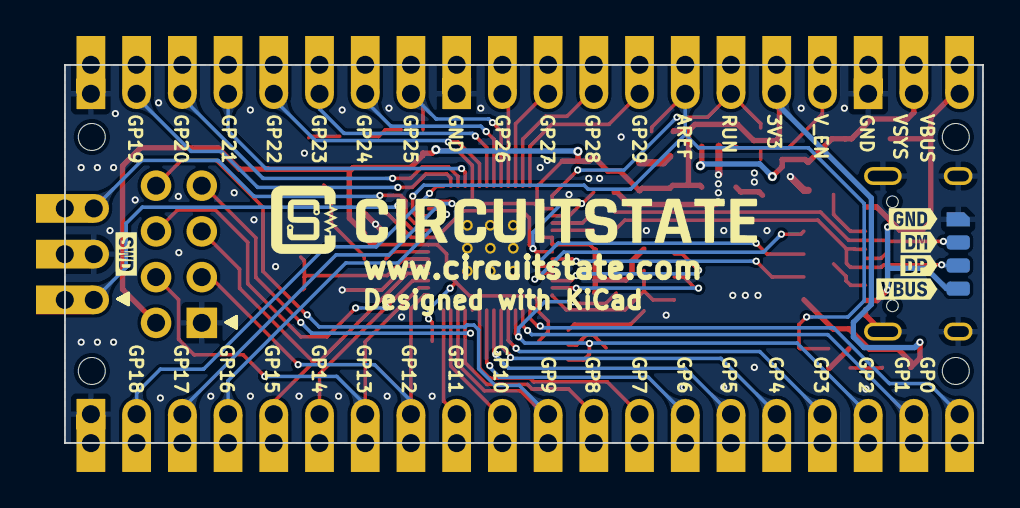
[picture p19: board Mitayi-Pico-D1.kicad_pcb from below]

Board: 2 copper layers, 51.0 x 21.0 mm, 73 parts (11 on the bottom side), 61 nets.

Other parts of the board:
kibuzzard-66CE1AA2: G***; kibuzzard-66CE1AA2
kibuzzard-66CE1AF9: G***; kibuzzard-66CE1AF9
kibuzzard-631DCCC7: G***; kibuzzard-631DCCC7
kibuzzard-631DCD0C: G***; kibuzzard-631DCD0C
kibuzzard-631DCDA0: G***; kibuzzard-631DCDA0
kibuzzard-631DCDB3: G***; kibuzzard-631DCDB3
kibuzzard-631DCE60: G***; kibuzzard-631DCE60
kibuzzard-632CA15B: G***; kibuzzard-632CA15B
kibuzzard-660C3D9D: G***; kibuzzard-660C3D9D
kibuzzard-680DBD8D: G***; kibuzzard-680DBD8D
kibuzzard-680DBD83: G***; kibuzzard-680DBD83
kibuzzard-680DBD88: G***; kibuzzard-680DBD88
kibuzzard-680DBD96: G***; kibuzzard-680DBD96
kibuzzard-680DBDCE: G***; kibuzzard-680DBDCE
kibuzzard-680DBDF9: G***; kibuzzard-680DBDF9
kibuzzard-680DC314: G***; kibuzzard-680DC314
kibuzzard-680DC361: G***; kibuzzard-680DC361
kibuzzard-66126165: G***; kibuzzard-66126165

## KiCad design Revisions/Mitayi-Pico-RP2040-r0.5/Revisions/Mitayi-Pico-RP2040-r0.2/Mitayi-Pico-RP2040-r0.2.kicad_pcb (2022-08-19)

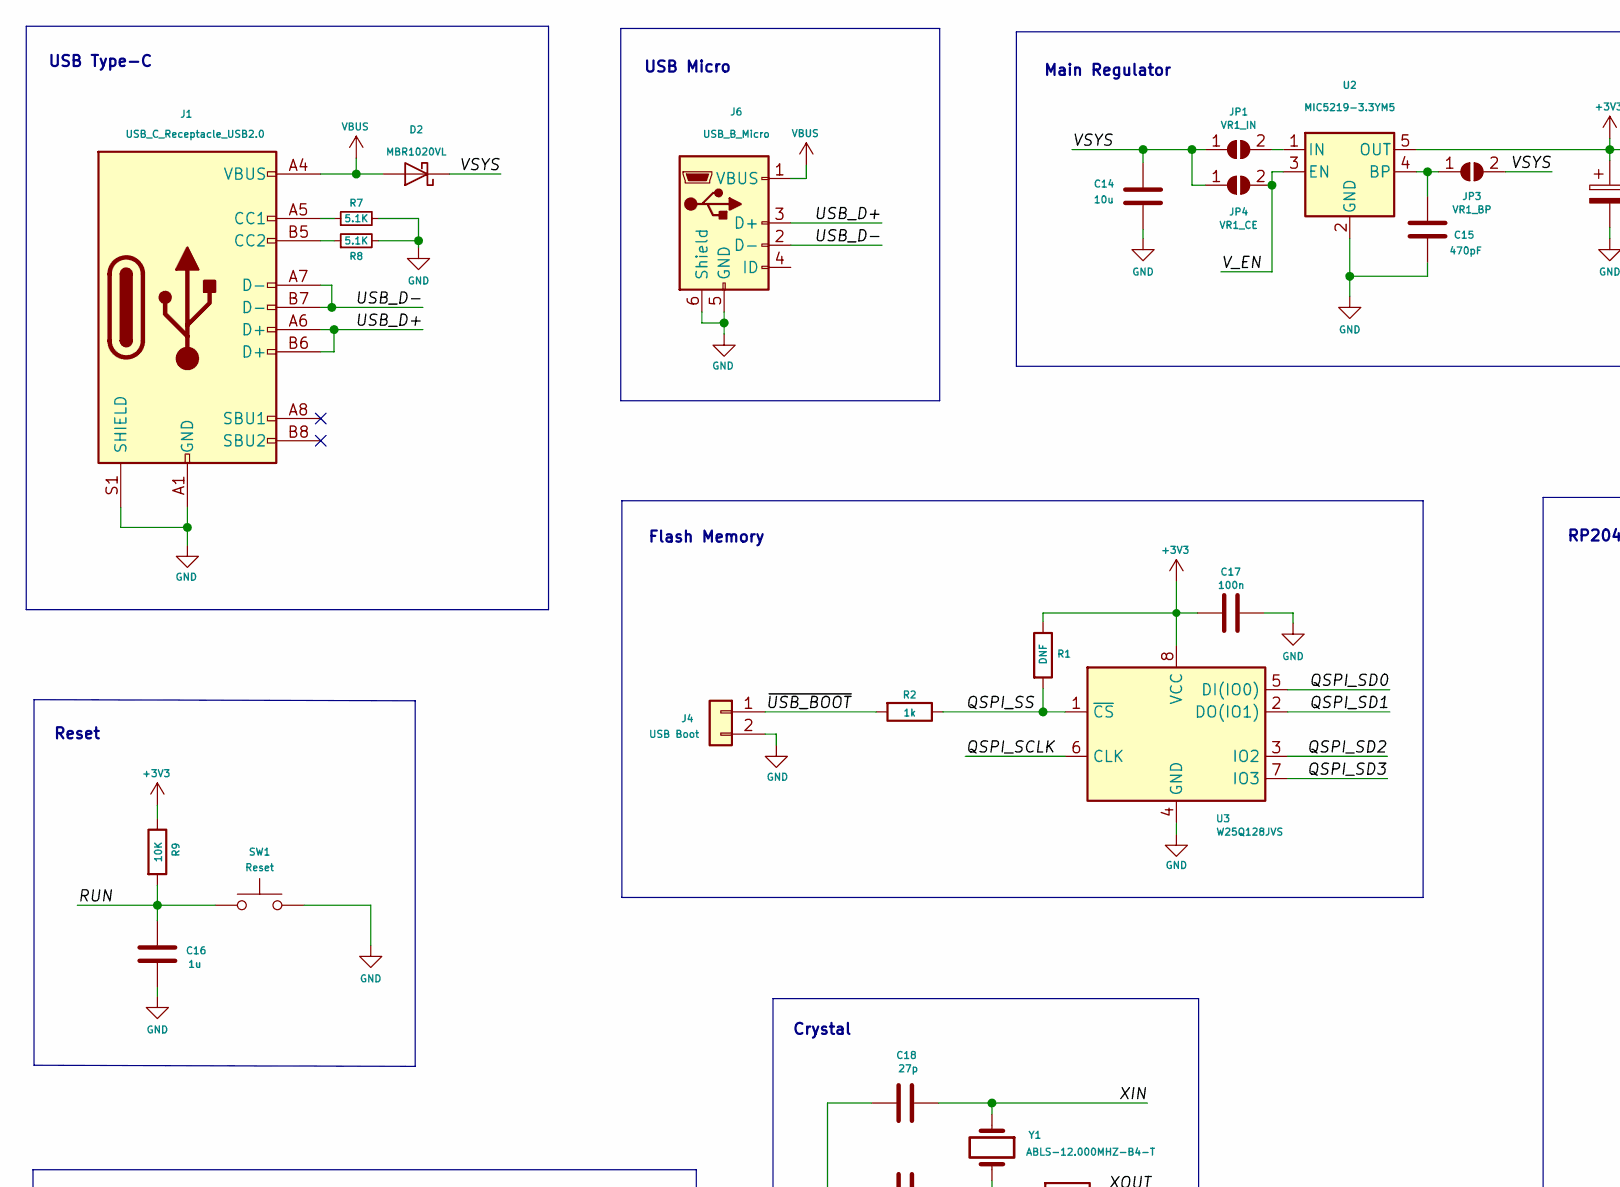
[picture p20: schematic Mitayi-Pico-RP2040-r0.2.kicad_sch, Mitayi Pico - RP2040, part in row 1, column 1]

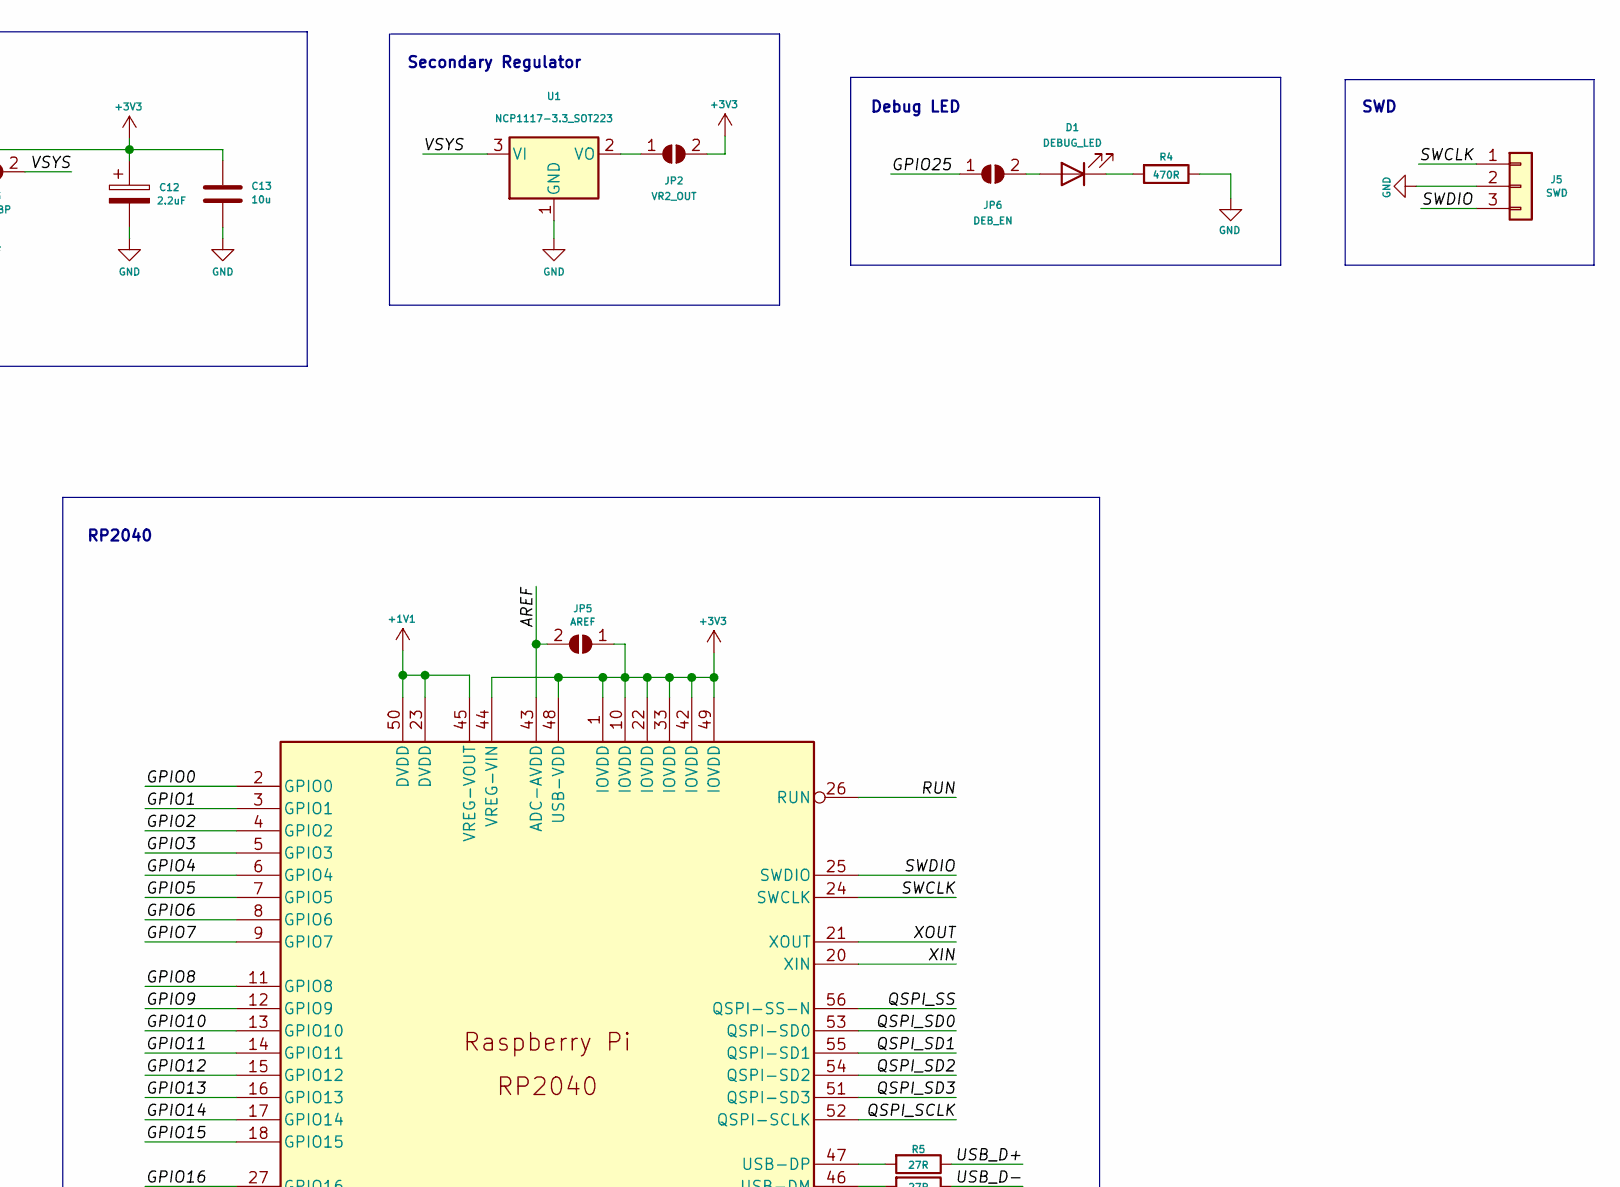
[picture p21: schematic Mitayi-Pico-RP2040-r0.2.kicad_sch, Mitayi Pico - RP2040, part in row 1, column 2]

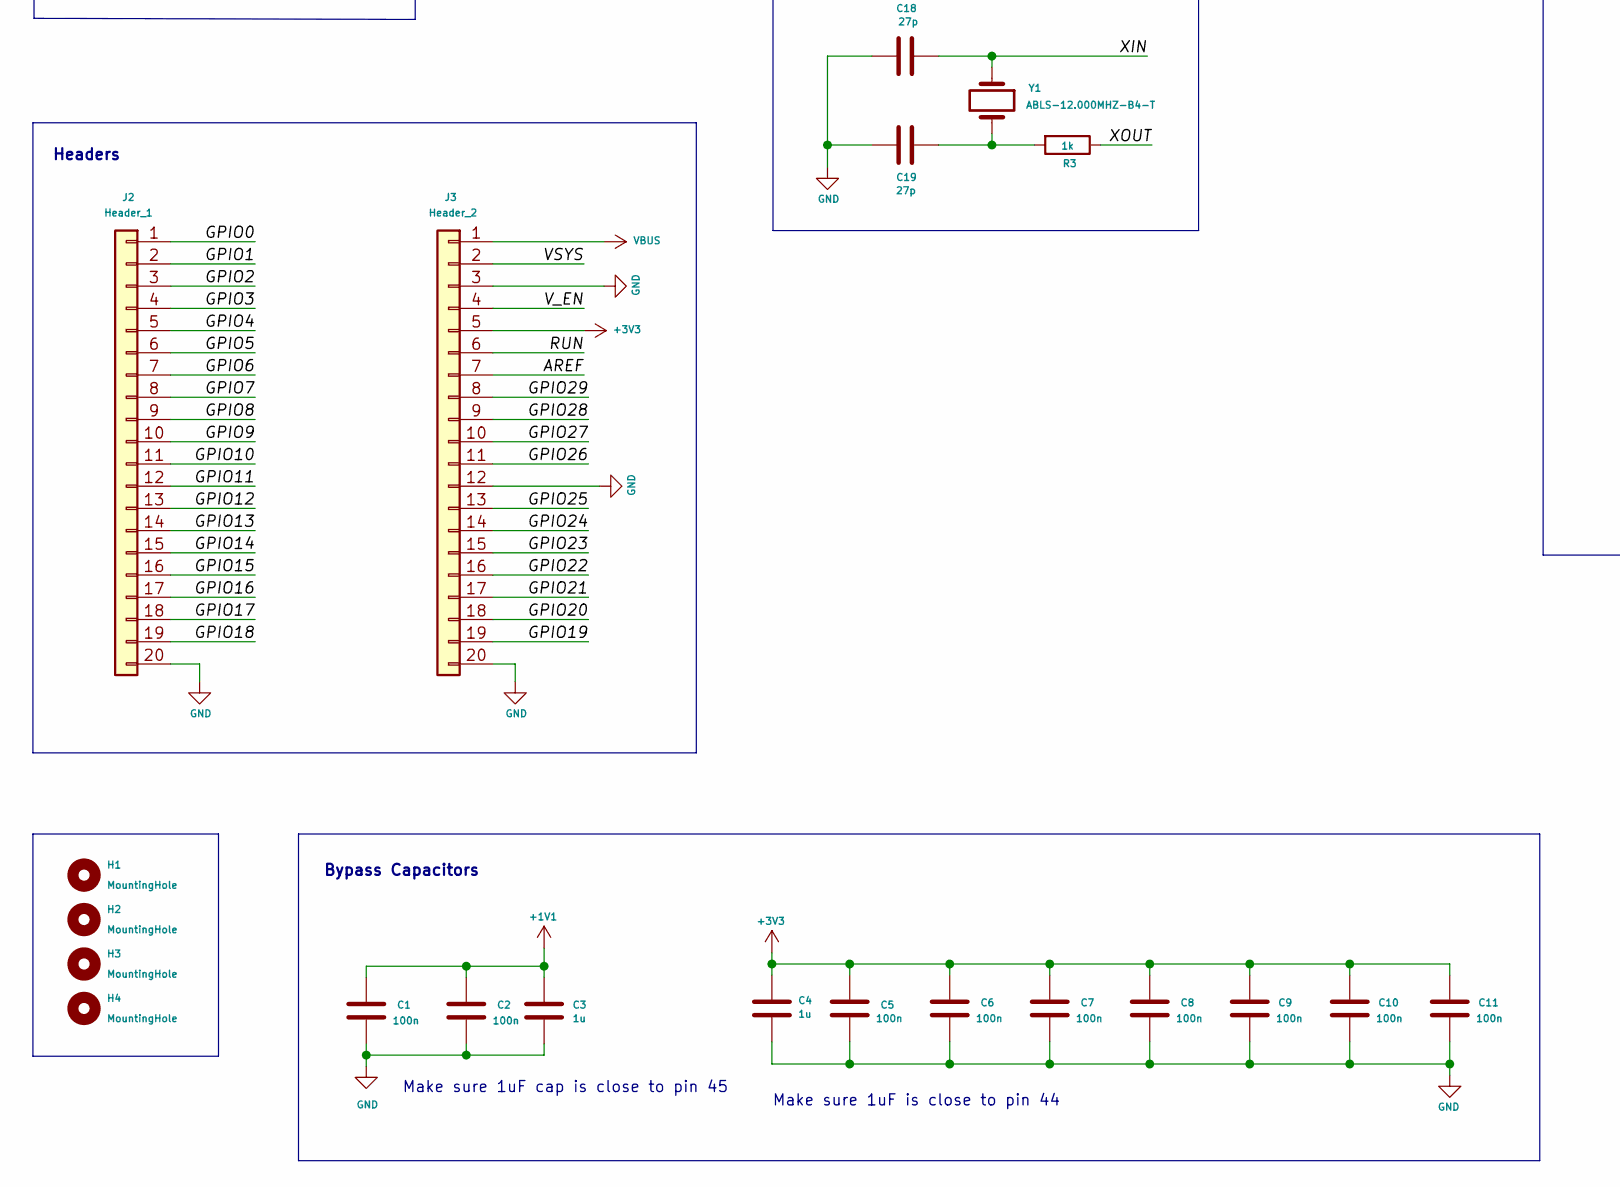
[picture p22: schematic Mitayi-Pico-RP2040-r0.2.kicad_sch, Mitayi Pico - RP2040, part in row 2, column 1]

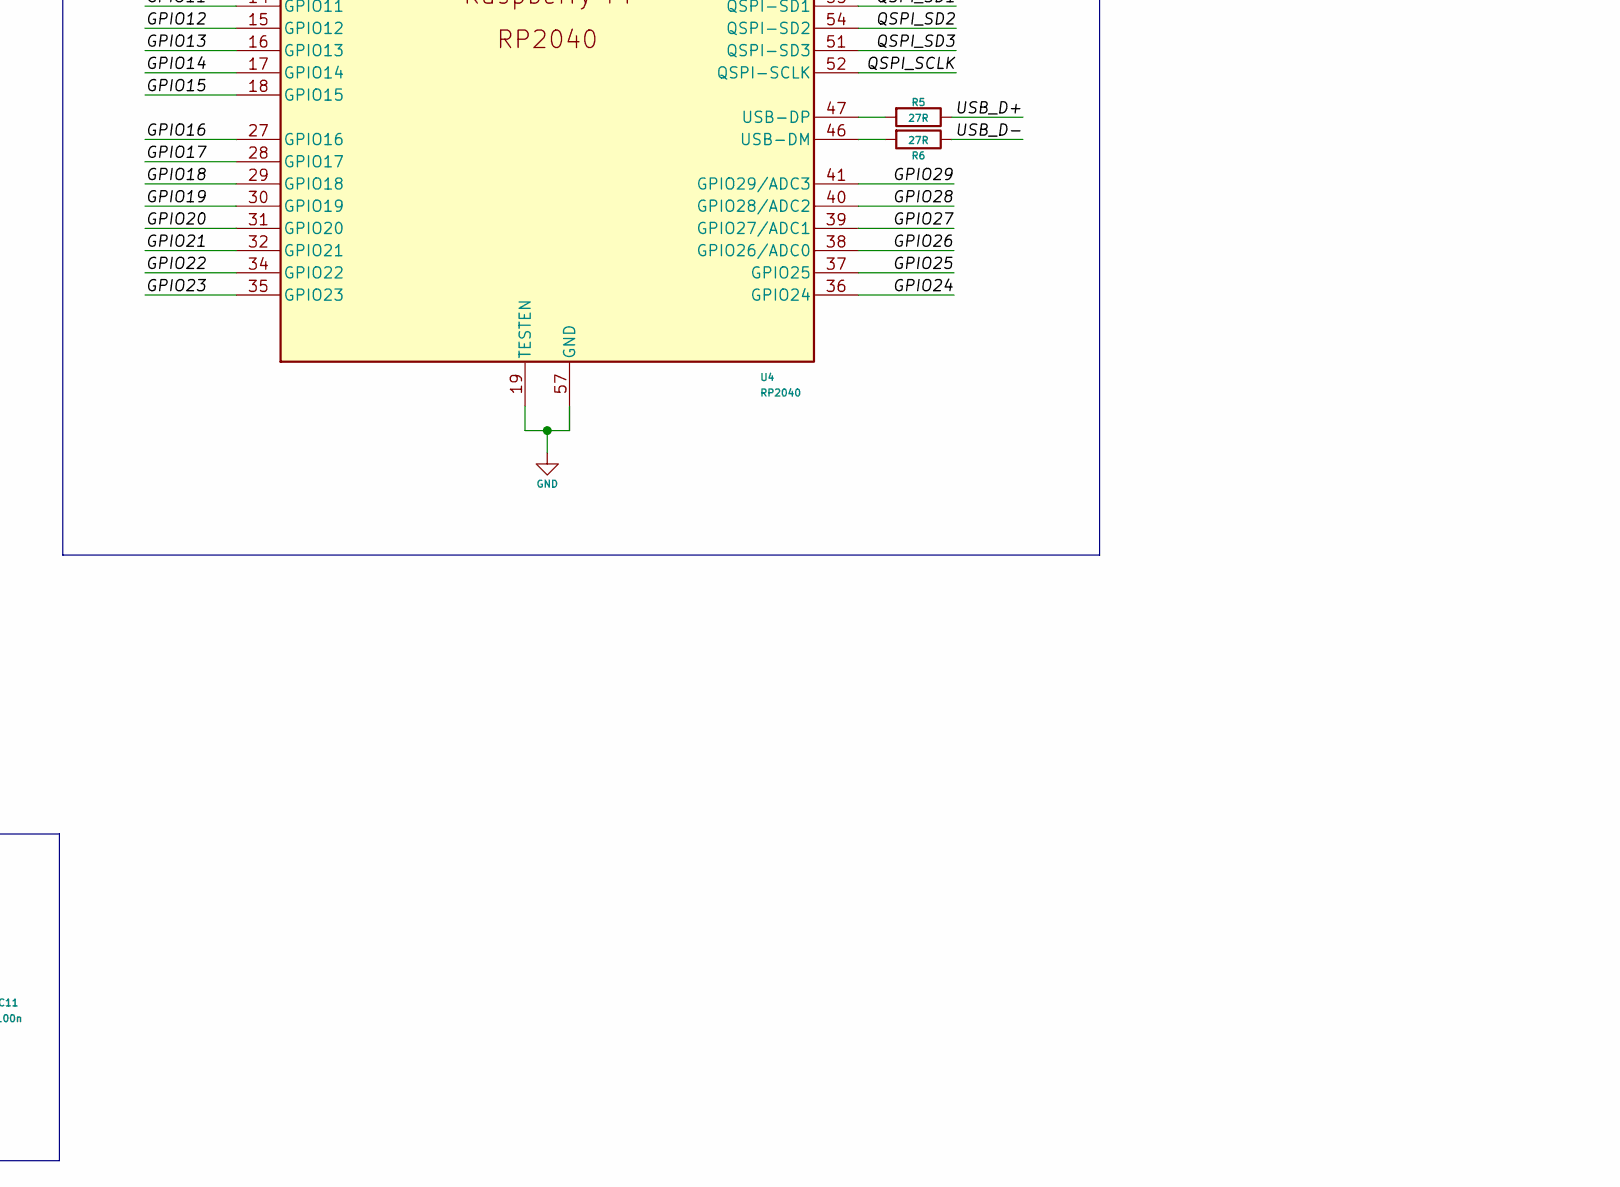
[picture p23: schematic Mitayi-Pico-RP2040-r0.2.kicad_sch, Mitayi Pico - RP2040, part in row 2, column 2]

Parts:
C1, C2, C5, C6, C7, C8, C9, C10, C11, C17: 100n; C_0402_1005Metric_Pad0.74x0.62mm_HandSolder
C3, C4, C16: 1u; C_0402_1005Metric_Pad0.74x0.62mm_HandSolder
C12: 2.2uF; CP_EIA-2012-12_Kemet-R
C13, C14: 10u; C_0603_1608Metric
C15: 470pF; C_0402_1005Metric_Pad0.74x0.62mm_HandSolder
C18, C19: 27p; C_0402_1005Metric_Pad0.74x0.62mm_HandSolder
D1: DEBUG_LED; C_0603_1608Metric_Pad1.08x0.95mm_HandSolder
D2: MBR1020VL; D_SOD-123F
H1, H2, H3, H4: MountingHole; MountingHole_2.2mm_M2
J1: USB_C_Receptacle_USB2.0; Korean-Hroparts-Elec_TYPE-C-31-M-12
J2: Header_1; PinHeader_1x20_2H_P2.54mm_Vertical
J3: Header_2; PinHeader_1x20_2H_P2.54mm_Vertical
J4: USB Boot; R_0603_1608Metric_Pad0.98x0.95mm_HandSolder
J5: SWD; PinHeader_1x03_P2.54mm_Vertical
J6: USB_B_Micro; USB_Micro-B_Molex-105017-0001
JP1: VR1_IN; R_0402_1005Metric
JP2: VR2_OUT; R_0402_1005Metric
JP3: VR1_BP; R_0402_1005Metric
JP4: VR1_CE; R_0402_1005Metric
JP5: AREF; R_0402_1005Metric
JP6: DEB_EN; R_0402_1005Metric
R1: DNF; R_0402_1005Metric_Pad0.72x0.64mm_HandSolder
R2, R3: 1k; R_0402_1005Metric_Pad0.72x0.64mm_HandSolder
R4: 470R; R_0402_1005Metric_Pad0.72x0.64mm_HandSolder
R5, R6: 27R; R_0402_1005Metric_Pad0.72x0.64mm_HandSolder
R7, R8: 5.1K; R_0402_1005Metric_Pad0.72x0.64mm_HandSolder
R9: 10K; R_0402_1005Metric_Pad0.72x0.64mm_HandSolder
SW1: Reset; CK_SW_SPST_UK-B0273-SP25Y
U1: NCP1117-3.3_SOT223; SOT-223-3_TabPin2
U2: MIC5219-3.3YM5; SOT-23-5
U3: W25Q128JVS; SOIC-8_5.23x5.23mm_P1.27mm
U4: RP2040; RP2040-QFN-56
Y1: ABLS-12.000MHZ-B4-T; Crystal_SMD_3225-4Pin_3.2x2.5mm

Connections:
+1V1: C1.1, C2.1, C3.1, U4.23 (DVDD), U4.45 (VREG-VOUT), U4.50 (DVDD)
+3V3: C4.1, C5.1, C6.1, C7.1, C8.1, C9.1, C10.1, C11.1, C12.1, C13.1, C17.1, J3.5, JP2.2 (B), JP5.1 (A), R1.1, R9.1, U2.5 (OUT), U3.8 (VCC), U4.1 (IOVDD), U4.10 (IOVDD), U4.22 (IOVDD), U4.33 (IOVDD), U4.42 (IOVDD), U4.44 (VREG-VIN), U4.48 (USB-VDD), U4.49 (IOVDD)
/AREF: J3.7, JP5.2 (B), U4.43 (ADC-AVDD)
/GPIO0: J2.1, U4.2 (GPIO0)
/GPIO1: J2.2, U4.3 (GPIO1)
/GPIO2: J2.3, U4.4 (GPIO2)
/GPIO3: J2.4, U4.5 (GPIO3)
/GPIO4: J2.5, U4.6 (GPIO4)
/GPIO5: J2.6, U4.7 (GPIO5)
/GPIO6: J2.7, U4.8 (GPIO6)
/GPIO7: J2.8, U4.9 (GPIO7)
/GPIO8: J2.9, U4.11 (GPIO8)
/GPIO9: J2.10, U4.12 (GPIO9)
/GPIO10: J2.11, U4.13 (GPIO10)
/GPIO11: J2.12, U4.14 (GPIO11)
/GPIO12: J2.13, U4.15 (GPIO12)
/GPIO13: J2.14, U4.16 (GPIO13)
/GPIO14: J2.15, U4.17 (GPIO14)
/GPIO15: J2.16, U4.18 (GPIO15)
/GPIO16: J2.17, U4.27 (GPIO16)
/GPIO17: J2.18, U4.28 (GPIO17)
/GPIO18: J2.19, U4.29 (GPIO18)
/GPIO19: J3.19, U4.30 (GPIO19)
/GPIO20: J3.18, U4.31 (GPIO20)
/GPIO21: J3.17, U4.32 (GPIO21)
/GPIO22: J3.16, U4.34 (GPIO22)
/GPIO23: J3.15, U4.35 (GPIO23)
/GPIO24: J3.14, U4.36 (GPIO24)
/GPIO25: J3.13, JP6.1 (A), U4.37 (GPIO25)
/GPIO26: J3.11, U4.38 (GPIO26/ADC0)
/GPIO27: J3.10, U4.39 (GPIO27/ADC1)
/GPIO28: J3.9, U4.40 (GPIO28/ADC2)
/GPIO29: J3.8, U4.41 (GPIO29/ADC3)
/QSPI_SCLK: U3.6 (CLK), U4.52 (QSPI-SCLK)
/QSPI_SD0: U3.5 (DI(IO0)), U4.53 (QSPI-SD0)
/QSPI_SD1: U3.2 (DO(IO1)), U4.55 (QSPI-SD1)
/QSPI_SD2: U3.3 (IO2), U4.54 (QSPI-SD2)
/QSPI_SD3: U3.7 (IO3), U4.51 (QSPI-SD3)
/QSPI_SS: R1.2, R2.1, U3.1 (~CS), U4.56 (QSPI-SS-N)
/RUN: C16.1, J3.6, R9.2, SW1.1, U4.26 (RUN)
/SWCLK: J5.1, U4.24 (SWCLK)
/SWDIO: J5.3, U4.25 (SWDIO)
/USB_D+: J1.A6 (D+), J1.B6 (D+), J6.3 (D+), R5.1
/USB_D-: J1.A7 (D-), J1.B7 (D-), J6.2 (D-), R6.1
/VSYS: C14.1, D2.1 (K), J3.2, JP1.1 (A), JP3.2 (B), JP4.1 (A), U1.3 (VI)
/V_EN: J3.4, JP4.2 (B), U2.3 (EN)
/XIN: C18.1, U4.20 (XIN), Y1.1
/XOUT: R3.1, U4.21 (XOUT)
/~USB_BOOT: J4.1, R2.2
GND: C1.2, C2.2, C3.2, C4.2, C5.2, C6.2, C7.2, C8.2, C9.2, C10.2, C11.2, C12.2, C13.2, C14.2, C15.2, C16.2, C17.2, C18.2, C19.2, J1.A1 (GND), J1.A12 (GND), J1.B1 (GND), J1.B12 (GND), J1.S1 (SHIELD), J2.20, J3.3, J3.12, J3.20, J4.2, J5.2, J6.5 (GND), J6.6 (Shield), R4.1, R7.2, R8.2, SW1.2, U1.1 (GND), U2.2 (GND), U3.4 (GND), U4.19 (TESTEN), U4.57 (GND)
unnamed: C15.1, JP3.1 (A), U2.4 (BP)
unnamed: C19.1, R3.2, Y1.2
unnamed: D1.1 (K), R4.2
unnamed: D1.2 (A), JP6.2 (B)
unnamed: J1.A5 (CC1), R7.1
unnamed: J1.B5 (CC2), R8.1
unnamed: JP1.2 (B), U2.1 (IN)
unnamed: JP2.1 (A), U1.2 (VO)
unnamed: R5.2, U4.47 (USB-DP)
unnamed: R6.2, U4.46 (USB-DM)
VBUS: D2.2 (A), J1.A4 (VBUS), J1.A9 (VBUS), J1.B4 (VBUS), J1.B9 (VBUS), J3.1, J6.1 (VBUS)

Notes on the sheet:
USB Type-C
Main Regulator
Headers
RP2040
Bypass Capacitors
Make sure 1uF cap is close to pin 45
Debug LED
Secondary Regulator
Crystal
SWD
Reset
Make sure 1uF is close to pin 44
Flash Memory
USB Micro

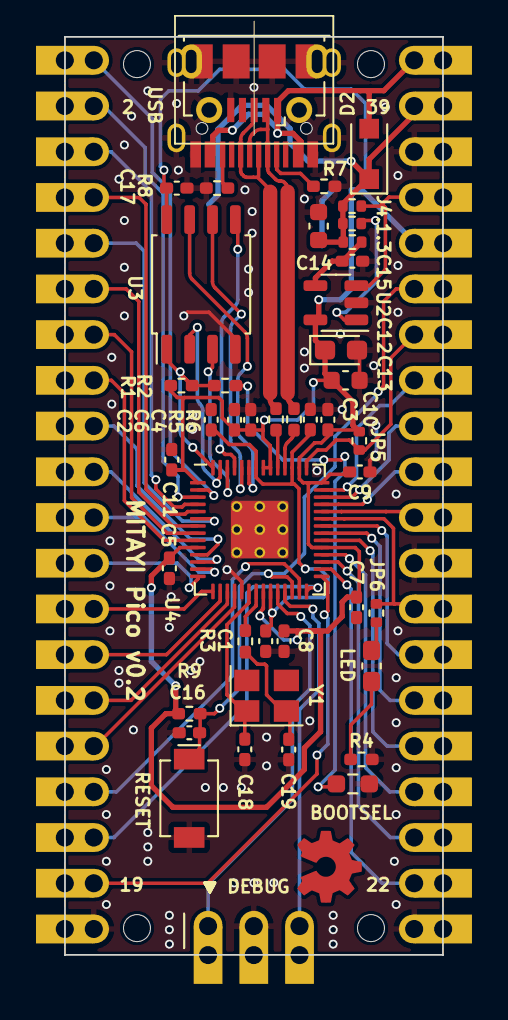
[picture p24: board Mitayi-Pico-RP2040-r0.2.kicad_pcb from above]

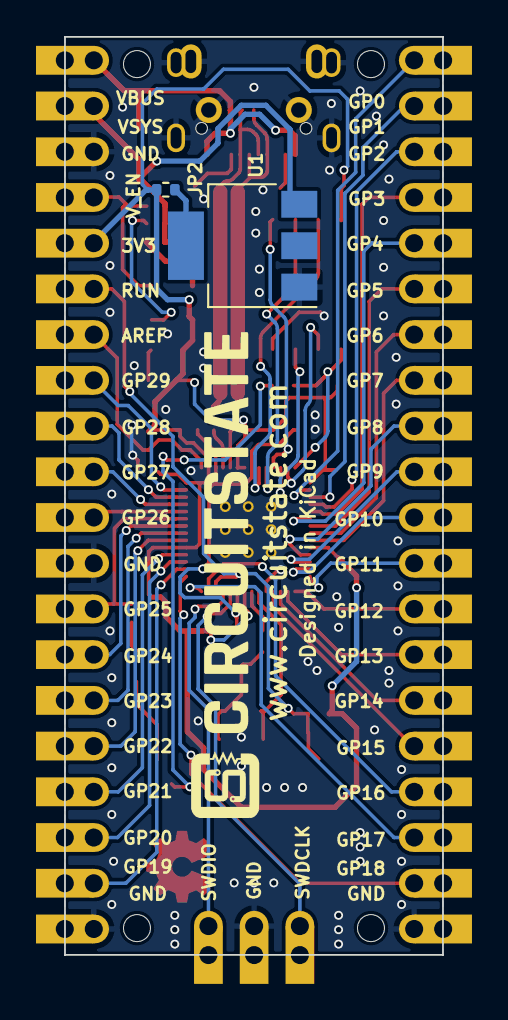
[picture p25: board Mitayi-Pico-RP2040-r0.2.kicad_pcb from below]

Board: 2 copper layers, 21.0 x 51.0 mm, 52 parts (3 on the bottom side), 61 nets.

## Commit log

2022-08-19 Saved r0.2
    [Amphenol-USB-Tyep-C-Receptacle-12401598E4#2A.STEP, C&K-Tactile-Switch-PTS820J20KPSMTRLFS.stp, Mitayi-Pico-LCSC-BoM-Export.xlsx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]
2022-08-19 Removed 3D shapes folder
    [Amphenol-USB-Tyep-C-Receptacle-12401598E4#2A.STEP, C&K-Tactile-Switch-PTS820J20KPSMTRLFS.stp, Molex-Micro-USB-Receptacle-1050170001.stp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]
2022-08-19 Updated exported files
    [Mitayi-Pico-LCSC-BoM-Export.xlsx, Mitayi-Pico-RP2040-Rev-0.2-BoM-27082021-1.xls, Mitayi-Pico-RP2040-Rev-0.2-BoM-CSV-27082021-1.csv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]
2022-08-19 Updated root design files
    [Mitayi-Pico-RP2040.kicad_pcb, Mitayi-Pico-RP2040.kicad_sch]
2022-08-19 Updated design info
    [Mitayi-Pico-RP2040.kicad_pcb, Mitayi-Pico-RP2040.kicad_sch]
2022-08-20 Exported files
    [Mitayi-Pico-RP2040-B_Courtyard.gbr, Mitayi-Pico-RP2040-B_Cu.gbr, Mitayi-Pico-RP2040-B_Fab.gbr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]
2022-09-05 r0.3
    Connected with CADLAB.io
    [ESP01-RP2040-Pin-Mapping.xlsx, Mitayi-Pico-RP2040.kicad_pcb, Mitayi-Pico-RP2040.kicad_sch]
2023-02-20 Revision r0.5
    [Amphenol-USB-Tyep-C-Receptacle-12401598E4#2A.STEP, C&K-Tactile-Switch-PTS820J20KPSMTRLFS.stp, ESP01-RP2040-Pin-Mapping.xlsx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]
2024-04-02 Updated to KiCad V8
    [Mitayi-Pico-LCSC-BoM-Export.xlsx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]
2024-04-02 Updated fab layers
    [Mitayi-Pico-RP2040-R0.6-BOM-CSV-02042024-1.csv, Mitayi-Pico-RP2040.kicad_pcb, Mitayi-Pico-RP2040.kicad_sch]
2024-04-07 R0.6
    * Added USB breakout pads.
    * Moved BTN jumper to Front.
    * Replaced jumpers with 0R.
    * Udpated fab layers.
    [Mitayi-Pico-RP2040.kicad_pcb, Mitayi-Pico-RP2040.kicad_sch]
2024-04-07 Generated mfr files
    [Mitayi-Pico-RP2040-R0.6-BOM-CSV-07042024-1.csv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]
2024-08-27 Updated logos and labels
    * Updated the silkscreen labels.
    * Added the `D1` variant string to the project info and silkscreen.
    * Added net classes and net highlights in the schematic and PCB.
    * Updated the placements of the OSHW logo.
    * Added `ALT MPN` column to the BoM.
    * Manufacturing files generation pending.
    [Mitayi-Pico-RP2040-R0.6-BoM-CSV-20042024-1.csv, Mitayi-Pico-RP2040.kicad_pcb, Mitayi-Pico-RP2040.kicad_sch]
2024-08-28 Removed the Micro-USB
    [Mitayi-Pico-RP2040.kicad_pcb, Mitayi-Pico-RP2040.kicad_sch]
2024-08-28 Generated manufacturing files
    - Replaced the USB-C connector with a custom one with paste layers on the THT pins. This will help in reliably soldering the USB-C connector.
    [Mitayi-Pico-D1-R0.6-BoM-CSV-28082024-1.csv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]
2024-08-28 Adjusted the PCB thickness
    * Adjusted the PCB thickness to 1 mm from 1.6 mm.
    * Since there are no changes in the designs, new manufacturing files won't be generated.
    [Mitayi-Pico-RP2040.kicad_pcb]
2025-04-27 Renamed project to `Mitayi-Pico-D1`
    - Renamed project to `Mitayi-Pico-D1`.
    - Schematic
    - Updated colors.
    - Added `VSYS` net class.
    - Added `Group by MPN-DNP` BoM preset.
    - PCB
    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
    [Mitayi-Pico-D1-R0.6-BoM-CSV-27042025-1.csv, Mitayi-Pico-D1-R0.6-BoM-CSV-28082024-1.csv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]

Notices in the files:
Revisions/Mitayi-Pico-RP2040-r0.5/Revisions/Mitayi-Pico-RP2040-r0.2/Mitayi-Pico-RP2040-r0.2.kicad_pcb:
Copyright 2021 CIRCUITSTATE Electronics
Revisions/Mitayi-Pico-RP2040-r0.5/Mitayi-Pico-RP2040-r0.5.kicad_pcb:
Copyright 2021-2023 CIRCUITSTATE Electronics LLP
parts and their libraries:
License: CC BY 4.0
